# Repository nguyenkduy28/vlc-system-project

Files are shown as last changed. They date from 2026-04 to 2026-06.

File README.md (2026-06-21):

# Hệ thống truyền thông ánh sáng nhìn thấy (VLC/OWC)

Đây là repository đồ án thiết kế hệ thống truyền thông quang không dây sử dụng ánh sáng nhìn thấy. Hệ thống gồm bo mạch phát/thu, firmware cho STM32F407VET6, chương trình giám sát trên máy tính và tài liệu phục vụ thiết kế, mô phỏng, đo kiểm.

## 1. Tổng quan hệ thống

Hệ thống truyền dữ liệu theo phương pháp điều chế OOK (On-Off Keying):

- Khối phát tạo sóng mang quang bằng PWM, đóng/ngắt sóng mang theo từng bit dữ liệu.
- Khối thu chuyển tín hiệu quang thành tín hiệu điện, tạo dữ liệu bit từ số cạnh thu được trong mỗi chu kỳ bit.
- STM32 thực hiện đóng gói frame, phát dữ liệu, đồng bộ frame thu, kiểm tra checksum và thống kê chất lượng liên kết.
- Máy tính giao tiếp với bo mạch qua UART để gửi lệnh, quan sát frame, điện áp, RTC, lỗi và các chỉ số BER/PER.

Định dạng frame hiện tại:

```text
AA AA AA | D5 | LEN | PAYLOAD | CHECKSUM
```

Trong đó:

- Preamble: 3 byte `0xAA`.
- Sync: `0xD5`.
- LEN: số byte payload, tối đa 32 byte.
- CHECKSUM: `(LEN + tổng các byte PAYLOAD) mod 256`.

Thông số mặc định của firmware:

| Thông số | Giá trị |
|---|---:|
| Vi điều khiển | STM32F407VET6 |
| Tốc độ bit | 100 kbit/s |
| Tần số tick TIM2 | 100 kHz |
| Sóng mang PWM TIM1 | khoảng 1 MHz |
| Ngưỡng nhận bit theo số cạnh | 6 cạnh/bit |
| Điện áp DAC threshold | 1650 mV |
| UART | 115200 baud |

## 2. Cấu trúc repository

```text
vlc-system-project/
├── firmware/   Firmware STM32CubeIDE cho STM32F407VET6
├── gui/        Các chương trình Python giao tiếp và giám sát UART
├── hardware/   Schematic, PCB, thư viện linh kiện và output Altium
├── ref/        Datasheet, tài liệu tham khảo, ảnh đo và kết quả mô phỏng
└── README.md   Tài liệu tổng quan repository
```

### `firmware/`

Project STM32CubeIDE chính nằm trong thư mục này.

- `OWC_Project.ioc`: cấu hình ngoại vi STM32CubeMX.
- `Core/Src/main.c`: khởi tạo ngoại vi và vòng lặp chương trình.
- `Core/Src/app_tasks.c`: điều phối ứng dụng, xử lý UART command và xuất log.
- `Core/Src/app_protocol.c`: định dạng frame và checksum.
- `Core/Src/vlc_tx.c`: phát frame OOK.
- `Core/Src/vlc_rx.c`: lấy mẫu tín hiệu thu và quản lý queue frame/lỗi.
- `Core/Src/rx_sync.c`: máy trạng thái đồng bộ và giải mã frame.
- `Core/Src/bsp_*.c`: UART, ADC monitor, DAC threshold và RTC.
- `Core/Inc/app_config.h`: các thông số cấu hình chính.
- `Drivers/`: thư viện HAL và CMSIS của STMicroelectronics.
- `Debug/`: output sinh ra khi build, không phải mã nguồn chính.

Các tài liệu luồng xử lý nằm tại:

- `firmware/overview.md`
- `firmware/flowtx.md`
- `firmware/flowrx.md`

### `gui/`

Các GUI được viết bằng Python/Tkinter, nhận log từ UART và hiển thị dữ liệu bằng Matplotlib.

Ba chương trình phù hợp với từng chế độ firmware:

| Chế độ firmware | GUI đề xuất |
|---|---|
| `APP_BOARD_ROLE_TX_ONLY` | `owc_tx_only_gui_v5_rtc.py` |
| `APP_BOARD_ROLE_RX_ONLY` | `owc_rx_only_gui_demo_v1.py` hoặc `owc_rx_monitor.py` |
| `APP_BOARD_ROLE_TX_RX_LOOPBACK` | `owc_loopback_gui_v2_tx_rx_tabs.py` |

Các file có hậu tố `v2`, `v3`, `fixed`, `demo` là các phiên bản phát triển được lưu lại để đối chiếu. Khi chạy thử nên chọn file mới nhất phù hợp với `APP_BOARD_ROLE`.

### `hardware/`

Thiết kế phần cứng được thực hiện bằng Altium Designer. Project chính:

```text
hardware/PCB_STM32F4/PCB_STM32F4.PrjPcb
```

Các sheet chính gồm:

- `BLOCK DIAGRAM.SchDoc`: sơ đồ khối hệ thống.
- `MCU INTERFACE.SchDoc`: STM32 và các kết nối ngoại vi.
- `Transmitter_MD.SchDoc`: mạch phát quang.
- `Receiver_VLC.SchDoc`: mạch thu quang.
- `PW SUPPLY.SchDoc`, `PWR_AFE.SchDoc`: nguồn và analog front-end.
- `VOLTAGE_MONITOR.SchDoc`: giám sát các đường nguồn.
- `UART TO USB LOG.SchDoc`: giao tiếp UART–USB.
- `PCB1.PcbDoc`: layout PCB.
- `VLC_SYSTEM.pdf`: bản xuất sơ đồ hệ thống.

Thư mục `History/` và `Project Outputs for PCB_STM32F4/` chứa lịch sử thiết kế và các báo cáo/output do Altium tạo.

### `ref/`

Chứa tài liệu phục vụ lựa chọn linh kiện và kiểm chứng thiết kế:

- Datasheet LED, photodiode, transistor, driver và IC nguồn.
- Tài liệu thiết kế transimpedance amplifier và mạch lọc.
- Tài liệu STM32F407.
- File mô phỏng TINA/Multisim.
- BOM, ảnh oscilloscope, ảnh PCB và sơ đồ trình tự hoạt động.

## 3. Build và nạp firmware

Yêu cầu:

- STM32CubeIDE.
- ST-LINK hoặc bộ nạp tương thích.
- Bo mạch sử dụng STM32F407VET6.

Các bước thực hiện:

1. Mở STM32CubeIDE và import thư mục `firmware/` dưới dạng project hiện có.
2. Chọn chế độ bo mạch trong `firmware/Core/Inc/app_config.h`:

   ```c
   #define APP_BOARD_ROLE APP_BOARD_ROLE_TX_ONLY
   // hoặc APP_BOARD_ROLE_RX_ONLY
   // hoặc APP_BOARD_ROLE_TX_RX_LOOPBACK
   ```

3. Build cấu hình Debug.
4. Kết nối ST-LINK, nạp chương trình và reset bo mạch.
5. Kết nối UART2 với máy tính ở baud rate `115200`.

Không thay đổi code trong `Drivers/` nếu không cần thiết. Các file chứa marker `USER CODE BEGIN/END` là file do STM32CubeMX quản lý; phần tùy chỉnh nên được đặt trong vùng user code để tránh mất khi generate lại.

## 4. Chạy GUI trên máy tính

Yêu cầu Python 3.9 trở lên. Cài các thư viện cần thiết:

```powershell
python -m pip install pyserial matplotlib
```

Ví dụ chạy GUI loopback:

```powershell
python gui/owc_loopback_gui_v2_tx_rx_tabs.py
```

Hoặc chạy GUI theo từng phía:

```powershell
python gui/owc_tx_only_gui_v5_rtc.py
python gui/owc_rx_only_gui_demo_v1.py
```

Sau khi GUI mở:

1. Chọn đúng cổng COM của bo mạch.
2. Đặt baud rate `115200`.
3. Nhấn **Connect**.
4. Kiểm tra log `role` để xác nhận GUI và firmware đang dùng cùng chế độ.

Các lệnh UART được firmware hỗ trợ gồm nhóm điều khiển TX (`tx_payload`, `tx_start`, `tx_stop`, `tx_single`, `tx_carrier_on`, `tx_carrier_off`, `tx_status`) và nhóm RTC (`rtc_get`, `rtc_set`, `rtc_reset`, `rtc_bkp`). Khả năng sử dụng lệnh TX phụ thuộc vào `APP_BOARD_ROLE`.

## 5. Log UART chính

Firmware xuất log định kỳ hoặc theo sự kiện:

| Log | Nội dung |
|---|---|
| `role` | Chế độ hiện tại của firmware |
| `alive_tx`, `alive_rx` | Bộ đếm và trạng thái hoạt động |
| `tx_frame` | Frame đang phát |
| `expected_tx_frame` | Frame tham chiếu ở phía thu |
| `last_rx`, `rx_frame` | Frame nhận gần nhất |
| `link_stats`, `link_quality` | BER, PER và thống kê payload |
| `err_summary`, `err_frame` | Thống kê và chi tiết lỗi |
| `adc_mv` | Điện áp các kênh giám sát |
| `dac_mv` | Điện áp ngưỡng comparator |
| `rtc` | Thời gian và trạng thái RTC/LSE/VBAT |

## 6. Kiểm thử cơ bản

### TX-only

- Kiểm tra PWM carrier tại đầu ra TIM1.
- Quan sát `tx_frame` và bộ đếm `tx_frames`.
- Thử `tx_start`, `tx_stop`, `tx_single` và thay payload.
- Đối chiếu tốc độ bit và dạng sóng OOK trên oscilloscope.

### RX-only

- Cấp tín hiệu quang từ bộ phát vào mạch thu.
- Theo dõi `last_edge_delta`, `last_raw_bit` và trạng thái FSM.
- Kiểm tra frame nhận, checksum, frame error và BER/PER.
- Điều chỉnh ngưỡng DAC khi chất lượng tín hiệu thay đổi.

### Loopback

- Build firmware với `APP_BOARD_ROLE_TX_RX_LOOPBACK`.
- So sánh trực tiếp frame TX và RX trong GUI loopback.
- Theo dõi lỗi theo vị trí bit, chất lượng liên kết và các đường nguồn.

## 7. Ghi chú

- Giá trị điện áp, ngưỡng cạnh và DAC cần được hiệu chỉnh theo phiên bản phần cứng và kết quả đo thực tế.
- Không commit thêm output build hoặc file tạm của IDE vào phần mã nguồn phát hành.
- Datasheet và tài liệu trong `ref/` thuộc về các nhà sản xuất hoặc tác giả tương ứng và chỉ được lưu để tham khảo kỹ thuật.

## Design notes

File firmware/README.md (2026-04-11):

# vlc-system-project
# VLC System Project

Graduation project for a Visible Light Communication system.

## Scope
This repository contains:
- Hardware design
- Firmware for STM32-based TX/RX
- PC software tools and GUI
- Test results and measurement data
- Project documentation

## Main modules
- Power management
- Optical transmitter
- Optical receiver
- ADC/comparator signal path
- STM32 firmware
- PC monitoring software

## Repository structure
- docs/: thesis, reports, block diagrams, datasheets
- hardware/: schematic, PCB, BOM, simulation, library
- firmware/: STM32 source code for TX/RX
- software/: PC tools, GUI, logger, analysis
- test/: BER, waveform, power, link validation
- production/: manufacturing outputs

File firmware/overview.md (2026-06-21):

# Overview Firmware OWC Project

Tài liệu này tóm tắt các phần quan trọng nhất của firmware OWC để dùng cho slide overview. Nội dung tập trung vào kiến trúc tổng quan, luồng TX/RX, FSM RX, giao tiếp UART, và các khối giám sát hệ thống.

---

## 1. Tổng quan kiến trúc firmware

Firmware được xây dựng trên STM32F407 và chia thành các khối chính:

- `main.c`: khởi tạo hệ thống và chạy vòng lặp chính.
- `app_tasks.c`: điều phối init, start, ISR dispatch, xử lý UART và log foreground.
- `vlc_tx.c`: phát frame OOK theo bit tick.
- `vlc_rx.c`: đọc edge-count TIM4, tạo raw bit và đẩy vào FSM RX.
- `rx_sync.c`: giải mã frame theo FSM.
- `app_protocol.c`: build frame và checksum dùng chung cho TX/RX.
- `bsp_uart.c`, `bsp_adc_monitor.c`, `bsp_dac_threshold.c`, `bsp_rtc.c`: dịch vụ nền.

```mermaid
%%{init: {"themeVariables": {"fontFamily": "Times New Roman", "fontSize": "18px"}}}%%
flowchart TD
    A["main.c"] --> B["app_tasks_init()"]
    B --> C["app_tasks_start()"]
    C --> D["TIM2 ISR"]
    D --> E["TX path"]
    D --> F["RX path"]
    C --> G["Foreground loop"]
    G --> H["UART logs"]
    G --> I["UART commands"]
    E --> J["TIM1 carrier OOK"]
    F --> K["TIM4 edge-count"]
    K --> L["rx_sync FSM"]
```

---

## 2. Cơ chế board role

Firmware hỗ trợ 3 chế độ biên dịch:

- `APP_BOARD_ROLE_TX_ONLY`
- `APP_BOARD_ROLE_RX_ONLY`
- `APP_BOARD_ROLE_TX_RX_LOOPBACK`

```mermaid
%%{init: {"themeVariables": {"fontFamily": "Times New Roman", "fontSize": "18px"}}}%%
flowchart TD
    A["TIM2 IRQ"] --> B{"APP_BOARD_ROLE?"}
    B -- "TX_ONLY" --> C["vlc_tx_on_bit_tick()"]
    B -- "RX_ONLY" --> D["vlc_rx_on_bit_tick()"]
    B -- "TX_RX_LOOPBACK" --> E["vlc_rx_on_bit_tick()"]
    E --> F["vlc_tx_on_bit_tick()"]
```

Ý nghĩa:

- `TX_ONLY`: chỉ phát, không chạy RX FSM trong ISR.
- `RX_ONLY`: chỉ thu, không phát bit trong ISR.
- `TX_RX_LOOPBACK`: chạy cả RX và TX, dùng cho kiểm thử nội bộ.

---

## 3. Flow phát TX

TX dùng điều chế OOK:

- bit `1` -> `TIM1 CCR1 = 84`
- bit `0` -> `TIM1 CCR1 = 0`

Frame TX:

```text
AA AA AA | D5 | LEN | PAYLOAD | CHECKSUM
```

```mermaid
%%{init: {"themeVariables": {"fontFamily": "Times New Roman", "fontSize": "18px"}}}%%
flowchart LR
    A["TIM2 tick"] --> B["vlc_tx_on_bit_tick()"]
    B --> C{"carrier_test?"}
    C -- "Yes" --> D["CCR1 = 84"]
    C -- "No" --> E{"tx_enabled?"}
    E -- "No" --> F["CCR1 = 0"]
    E -- "Yes" --> G{"bit = 1?"}
    G -- "Yes" --> H["CCR1 = 84"]
    G -- "No" --> I["CCR1 = 0"]
    H --> J["Advance bit index"]
    I --> J
    J --> K{"End of frame?"}
    K -- "No" --> L["Next tick"]
    K -- "Yes" --> M["Reset index + tx_frames++"]
```

---

## 4. Flow thu RX

RX dùng TIM4 đếm cạnh trên PB6.

Mỗi `TIM2` tick:

1. Đọc counter TIM4.
2. Tính `edge_delta`.
3. So sánh với `APP_RX_EDGE_THRESHOLD = 6`.
4. Tạo `raw_bit`.
5. Đẩy vào `rx_sync_on_tick()`.

```mermaid
%%{init: {"themeVariables": {"fontFamily": "Times New Roman", "fontSize": "18px"}}}%%
flowchart TD
    A["TIM2 tick"] --> B["Read TIM4 counter"]
    B --> C["Compute edge_delta"]
    C --> D{"edge_delta >= 6?"}
    D -- "Yes" --> E["raw_bit = 1"]
    D -- "No" --> F["raw_bit = 0"]
    E --> G["rx_sync_on_tick()"]
    F --> G
    G --> H{"Frame result?"}
    H -- "Valid" --> I["Push RX queue"]
    H -- "Frame error" --> J["Push error event"]
    H -- "Checksum error" --> K["Push error event"]
```

---

## 5. FSM đồng bộ RX

FSM RX là phần quan trọng nhất của khối thu.

Các state:

- `RX_SYNC_WAIT_ACTIVITY`
- `RX_SYNC_DETECT_PREAMBLE`
- `RX_SYNC_LOCK_BIT_TIMING`
- `RX_SYNC_READ_SYNC`
- `RX_SYNC_READ_LEN`
- `RX_SYNC_READ_PAYLOAD`
- `RX_SYNC_READ_CHECKSUM`

```mermaid
%%{init: {"themeVariables": {"fontFamily": "Times New Roman", "fontSize": "18px"}}}%%
stateDiagram-v2
    [*] --> WAIT_ACTIVITY
    WAIT_ACTIVITY --> DETECT_PREAMBLE : raw_bit=1
    WAIT_ACTIVITY --> WAIT_ACTIVITY : raw_bit=0

    DETECT_PREAMBLE --> READ_SYNC : found 0xAAAAAA
    DETECT_PREAMBLE --> DETECT_PREAMBLE : continue shift

    READ_SYNC --> READ_LEN : sync = 0xD5
    READ_SYNC --> WAIT_ACTIVITY : sync error

    READ_LEN --> READ_PAYLOAD : len valid
    READ_LEN --> WAIT_ACTIVITY : length error

    READ_PAYLOAD --> READ_CHECKSUM : payload done
    READ_CHECKSUM --> WAIT_ACTIVITY : checksum checked
```

Checksum:

```text
CHECKSUM = (LEN + sum(PAYLOAD)) mod 256
```

Frame hợp lệ được đẩy vào queue để foreground loop log ra `last_rx`, `rx_frame`, `link_stats`, `link_quality`.

---

## 6. UART log và command

Firmware không in log trong ISR. Tất cả log và command được xử lý ở foreground loop.

```mermaid
%%{init: {"themeVariables": {"fontFamily": "Times New Roman", "fontSize": "18px"}}}%%
flowchart TD
    A["UART byte"] --> B["Line buffer"]
    B --> C["Command line"]
    C --> D{"RTC command?"}
    D -- "Yes" --> E["rtc_get / rtc_set / rtc_reset / rtc_bkp"]
    D -- "No" --> F{"TX-capable role?"}
    F -- "TX_ONLY / TX_RX_LOOPBACK" --> G["tx_payload / tx_start / tx_stop / tx_single"]
    F -- "RX_ONLY" --> H["Ignore TX command"]
    E --> I["Print response"]
    G --> I
    H --> I
```

Nhóm lệnh TX được hỗ trợ trong cả `APP_BOARD_ROLE_TX_ONLY` và
`APP_BOARD_ROLE_TX_RX_LOOPBACK`. Riêng `APP_BOARD_ROLE_RX_ONLY` không có khối
phát nên firmware bỏ qua các lệnh TX và trả response lỗi command không hỗ trợ.

Các log chính:

- `role ...`
- `alive_tx ...` hoặc `alive_rx ...`
- `tx_frame ...`
- `expected_tx_frame ...`
- `last_rx ...`
- `rx_frame ...`
- `link_stats ...`
- `link_quality ...`
- `err_summary ...`
- `adc_mv ...`
- `dac_mv ...`
- `rtc ...`

---

## 7. Khối giám sát hệ thống

Hai khối nền giúp theo dõi trạng thái board:

- ADC monitor:
  - `rx_out_a`
  - `vmon_bu`
  - `vmon_bu_3v`
  - `vmon_main_sys`
  - `vmon_main`
  - `vmon_5v_sys`
  - `vmon_3v3_sys`
- DAC threshold:
  - mặc định `1650 mV`
- RTC:
  - dùng LSE `32.768 kHz`
  - backup register để giữ trạng thái thời gian khi VBAT còn

```mermaid
%%{init: {"themeVariables": {"fontFamily": "Times New Roman", "fontSize": "18px"}}}%%
flowchart LR
    A["ADC monitor"] --> B["adc_mv"]
    C["DAC threshold"] --> D["dac_mv"]
    E["RTC LSE/VBAT"] --> F["rtc"]
```

---

## 8. Điểm nhấn để đưa vào slide

Nếu chỉ chọn phần quan trọng nhất cho slide overview, nên ưu tiên:

1. Kiến trúc firmware.
2. Cơ chế board role.
3. Flow TX OOK.
4. Flow RX edge-count.
5. FSM RX.
6. UART log và command.

Đây là các phần thể hiện rõ nhất cách firmware vận hành và đủ để người xem hiểu hệ thống ngay từ cái nhìn đầu.

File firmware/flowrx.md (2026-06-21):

# RX Flow - OWC Project

Tài liệu này mô tả luồng xử lý RX của firmware truyền thông quang OWC trên STM32F407. Nội dung tập trung vào chế độ `APP_BOARD_ROLE_RX_ONLY`, đồng thời vẫn nêu rõ phần dùng chung với chế độ loopback để tiện cho report kỹ thuật và debug hệ thống.

---

## 1. Tổng quan

Luồng RX trong firmware được chia thành các phần chính:

1. Khởi tạo hệ thống, bật các ngoại vi hỗ trợ thu và giám sát.
2. Đọc xung cạnh từ `TIM4` trên chân `PB6`.
3. Mỗi nhịp `TIM2`, chuyển số cạnh đo được thành `raw_bit`.
4. Đưa `raw_bit` vào máy trạng thái `rx_sync`.
5. Nếu frame hợp lệ, đẩy vào queue để xử lý ở foreground.
6. Nếu lỗi sync hoặc checksum, tạo error event để log sau trong main loop.

Các ràng buộc kỹ thuật chính của khối RX:

* `TIM4` dùng edge-count để đếm cạnh từ tín hiệu thu.
* `APP_RX_EDGE_THRESHOLD = 6` dùng để chuyển delta cạnh thành bit 0/1.
* `TIM2` vẫn là bit tick 100 kHz.
* RX không in UART trong ISR.
* Các frame hợp lệ và frame lỗi đều được đưa ra foreground loop để log, tránh làm nặng ngắt.

---

## 2. Các khối chính trong luồng RX

| Khối | Vai trò |
| --- | --- |
| `main.c` | Khởi tạo hệ thống và chạy vòng lặp chính |
| `app_tasks.c/h` | Điều phối init, start, ISR theo board role, xử lý log UART |
| `vlc_rx.c/h` | Đọc TIM4, tạo raw bit, quản lý queue frame và error event |
| `rx_sync.c/h` | FSM đồng bộ preamble, sync, length, payload, checksum |
| `app_protocol.c/h` | Cung cấp payload/frame chuẩn để so sánh |
| `vlc_tx.c/h` | Cung cấp frame TX snapshot cho log so sánh và thống kê |
| `bsp_uart.c/h` | In log và nhận command UART |
| `bsp_adc_monitor.c/h` | Giám sát điện áp hệ thống |
| `bsp_dac_threshold.c/h` | Theo dõi ngưỡng DAC |
| `bsp_rtc.c/h` | Cung cấp timestamp cho log |

Trong chế độ `APP_BOARD_ROLE_RX_ONLY`, khối RX là thành phần trung tâm. Firmware vẫn giữ các khối hỗ trợ như ADC, DAC và RTC để phục vụ giám sát hệ thống và đồng bộ log.

---

## 3. Luồng khởi động RX

Khi firmware bắt đầu chạy, `main.c` thực hiện các bước khởi tạo HAL, clock hệ thống, GPIO và các ngoại vi cần thiết. Sau đó, `app_tasks_init()` khởi tạo các module ứng dụng, bao gồm UART, RTC, ADC monitor, DAC threshold, TX và RX. Tiếp theo, `app_tasks_start()` bật các runtime module theo `APP_BOARD_ROLE`.

```mermaid
%%{init: {"themeVariables": {"fontFamily": "Times New Roman", "fontSize": "18px"}}}%%
flowchart TD
    A["main()"] --> B["HAL_Init()"]
    B --> C["SystemClock_Config()"]
    C --> D["GPIO Init"]
    D --> E["DMA Init"]
    E --> F["TIM1 Init"]
    F --> G["TIM2 Init"]
    G --> H["ADC1 Init"]
    H --> I["UART2 Init"]
    I --> J["DAC Init"]
    J --> K["TIM4 Init"]
    K --> L["app_tasks_init()"]
    L --> L1["bsp_uart_init()"]
    L1 --> L2["bsp_rtc_init()"]
    L2 --> L3["bsp_adc_monitor_init()"]
    L3 --> L4["bsp_dac_threshold_init()"]
    L4 --> L5["vlc_tx_init()"]
    L5 --> L6["vlc_rx_init()"]
    L6 --> M["app_tasks_start()"]
    M --> N["Set DAC threshold"]
    N --> O["Start ADC monitor"]
    O --> P{"Board role?"}
    P -- "RX_ONLY" --> Q["Start RX module"]
    P -- "TX_RX_LOOPBACK" --> R["Start TX + RX modules"]
    P -- "TX_ONLY" --> S["Start TX module"]
    Q --> T["Start TIM2 interrupt"]
    R --> T
    S --> T
    T --> U["Main loop"]
    U --> V["app_tasks_process()"]
```

**Hình x. Luồng khởi động firmware khi chạy theo nhánh RX.**

Trong chế độ RX, `vlc_rx_init(htim4)` thiết lập queue frame, queue error event và reset trạng thái FSM. `vlc_rx_start()` sau đó khởi động `TIM4` ở chế độ edge-count để đo số cạnh của tín hiệu quang thu được.

---

## 4. Luồng thu bit RX

Mỗi lần `TIM2` phát sinh ngắt, firmware gọi callback timer. Trong chế độ `APP_BOARD_ROLE_RX_ONLY`, ISR chỉ gọi `vlc_rx_on_bit_tick()` để lấy mẫu cửa sổ bit hiện tại từ `TIM4`.

```mermaid
%%{init: {"themeVariables": {"fontFamily": "Times New Roman", "fontSize": "18px"}}}%%
flowchart TD
    A["TIM2 IRQ"] --> B["Timer callback"]
    B --> C["Read TIM4 counter"]
    C --> D["Compute edge delta"]
    D --> E{"delta >= threshold?"}
    E -- "Yes" --> F["raw_bit = 1"]
    E -- "No" --> G["raw_bit = 0"]
    F --> H["Update RX stats"]
    G --> H
    H --> I["rx_sync_on_tick(raw_bit)"]
    I --> J{"Frame result?"}
    J -- "Valid frame" --> K["Push to RX queue"]
    J -- "Frame error" --> L["Push error event"]
    J -- "Checksum error" --> M["Push checksum event"]
    K --> N["End ISR"]
    L --> N
    M --> N
```

**Hình x. Lưu đồ xử lý bit RX trong mỗi chu kỳ ngắt TIM2.**

Ở mỗi nhịp, firmware đọc giá trị counter của `TIM4`, tính chênh lệch so với lần đọc trước, rồi so sánh với `APP_RX_EDGE_THRESHOLD = 6`. Nếu số cạnh đủ lớn, bit được suy ra là `1`, ngược lại là `0`. Cách làm này giúp RX không cần lấy mẫu biên độ analog trực tiếp, mà dựa vào số cạnh thu được từ đường quang.

---

## 5. Cấu trúc frame RX

RX giải mã frame theo cùng định dạng với TX:

```text
AA AA AA | D5 | LEN | PAYLOAD | CHECKSUM
```

Trong đó:

| Trường | Ý nghĩa |
| --- | --- |
| `AA AA AA` | Preamble để phát hiện khung bắt đầu |
| `D5` | Sync byte |
| `LEN` | Độ dài payload |
| `PAYLOAD`  | Dữ liệu cần nhận |
| `CHECKSUM` | Byte kiểm tra lỗi |

```mermaid
%%{init: {"themeVariables": {"fontFamily": "Times New Roman", "fontSize": "18px"}}}%%
flowchart LR
    A["Preamble 1"] --> B["Preamble 2"]
    B --> C["Preamble 3"]
    C --> D["Sync byte"]
    D --> E["Length"]
    E --> F["Payload"]
    F --> G["Checksum"]
```

**Hình x. Cấu trúc frame thu được bởi khối RX.**

RX dùng cùng công thức checksum với TX:

```text
CHECKSUM = (LEN + sum(PAYLOAD)) mod 256
```

Với payload mặc định `55 A5 3C C3`, frame hợp lệ sẽ có checksum `FD`.

---

## 6. Máy trạng thái đồng bộ RX

Khối `rx_sync` là trung tâm của luồng RX. Nó nhận `raw_bit` từ `vlc_rx_on_bit_tick()` và giải mã dần thành byte, rồi thành frame.

Các trạng thái chính:

| State | Ý nghĩa |
| ----- | --- |
| `RX_SYNC_WAIT_ACTIVITY` | Chờ có hoạt động trên đường RX |
| `RX_SYNC_DETECT_PREAMBLE` | Tìm chuỗi `AA AA AA` bằng shift 24-bit |
| `RX_SYNC_LOCK_BIT_TIMING` | Trạng thái khóa bit timing trung gian |
| `RX_SYNC_READ_SYNC` | Đọc byte sync `D5` |
| `RX_SYNC_READ_LEN` | Đọc độ dài payload |
| `RX_SYNC_READ_PAYLOAD` | Đọc các byte payload |
| `RX_SYNC_READ_CHECKSUM` | Đọc byte checksum và kiểm tra |

```mermaid
%%{init: {"themeVariables": {"fontFamily": "Times New Roman", "fontSize": "18px"}}}%%
stateDiagram-v2
    [*] --> WAIT_ACTIVITY
    WAIT_ACTIVITY --> DETECT_PREAMBLE : raw_bit = 1
    WAIT_ACTIVITY --> WAIT_ACTIVITY : raw_bit = 0

    DETECT_PREAMBLE --> READ_SYNC : found 0xAAAAAA
    DETECT_PREAMBLE --> DETECT_PREAMBLE : not found

    READ_SYNC --> READ_LEN : value = 0xD5
    READ_SYNC --> WAIT_ACTIVITY : sync error

    READ_LEN --> READ_PAYLOAD : 1..APP_MAX_PAYLOAD_LEN
    READ_LEN --> WAIT_ACTIVITY : length error

    READ_PAYLOAD --> READ_CHECKSUM : enough bytes
    READ_CHECKSUM --> WAIT_ACTIVITY : checksum done
```

**Hình x. FSM đồng bộ và giải mã frame RX.**

Hai điểm quan trọng trong FSM:

1. `WAIT_ACTIVITY` không làm mất bit `1` đầu tiên khi bắt đầu preamble.
2. Sau khi phát hiện `AA AA AA`, FSM chuyển sang `READ_SYNC` mà không bỏ mất bit kế tiếp.

Khi `READ_CHECKSUM` nhận đủ byte cuối:

* Nếu checksum đúng, `result.has_frame = 1`.
* Nếu sai checksum, `result.checksum_error = 1`.
* Nếu sai sync hoặc sai length, `result.frame_error = 1`.

---

## 7. Luồng xử lý frame hợp lệ và lỗi

```mermaid
%%{init: {"themeVariables": {"fontFamily": "Times New Roman", "fontSize": "18px"}}}%%
flowchart TD
    A["rx_sync_on_tick()"] --> B{"has_frame?"}
    B -- "Yes" --> C["Increment rx_frames"]
    C --> D["Push valid frame to queue"]
    B -- "No" --> E{"frame_error?"}
    E -- "Yes" --> F["Increment frame_errors"]
    F --> G["Push frame error event"]
    E -- "No" --> H{"checksum_error?"}
    H -- "Yes" --> I["Increment checksum_errors"]
    I --> J["Push checksum error event"]
    H -- "No" --> K["No event"]
```

**Hình x. Xử lý kết quả sau khi FSM giải mã một bit window.**

Khi một frame hợp lệ xuất hiện, `vlc_rx.c` đẩy frame vào queue valid frame và gán `rx_frame_id` theo bộ đếm quan sát riêng `s_rx_observed_frames`. Nếu là lỗi, firmware không in UART ngay trong ISR mà đẩy error event sang queue riêng để xử lý ở foreground loop.

---

## 8. Luồng UART điều khiển và log RX

UART command được xử lý trong foreground loop tại `app_tasks_process()`. Firmware không xử lý UART trong ISR để tránh blocking và để giữ `TIM2` ngắn.

```mermaid
%%{init: {"themeVariables": {"fontFamily": "Times New Roman", "fontSize": "18px"}}}%%
flowchart TD
    A["UART RX byte"] --> B["Line buffer"]
    B --> C["Command line"]
    C --> D{"RTC command?"}
    D -- "Yes" --> E["Handle RTC command"]
    D -- "No" --> F{"Board role RX_ONLY?"}
    F -- "Yes" --> G["RX processing only"]
    F -- "No" --> H["Loopback / TX path"]
    E --> I["Print response"]
    G --> I
    H --> I
```

**Hình x. Luồng xử lý UART command trong foreground loop.**

Các log chính của RX gồm:

```text
role board_role=RX_ONLY
alive_rx rx_frames=<N> frame_errors=<N> checksum_errors=<N> rx_sync_state=<N> last_edge_delta=<N> last_raw_bit=<N>
expected_tx_frame len=<N> payload=<HEX...> checksum=<XX> frame=<HEX...>
last_rx len=<N> payload=<HEX...>
rx_frame rx_frame_id=<N> len=<N> payload=<HEX...> checksum=<XX> frame=<HEX...>
link_stats payload_bits=<N> payload_bit_errors=<N> payload_ber_ppm=<N> invalid_frames=<N> payload_mismatch_frames=<N> good_payload_frames=<N>
link_quality rx_total_observed=<N> per_ppm=<N>
err_summary queued=<N> printed=<N> suppressed=<N>
err_frame ...
err_bits ...
adc_mv ...
dac_mv threshold=1650
rtc ...
```

Log `expected_tx_frame` rất quan trọng trong chế độ RX_ONLY vì board RX không phát dữ liệu thật, nhưng vẫn cần biết frame chuẩn để so sánh và tính thống kê chất lượng liên kết.

---

## 9. Queue frame và error event

RX dùng hai queue riêng:

1. Queue frame hợp lệ: chứa các frame decode thành công.
2. Queue error event: chứa event lỗi để log ở foreground loop.

```mermaid
%%{init: {"themeVariables": {"fontFamily": "Times New Roman", "fontSize": "18px"}}}%%
flowchart LR
    A["Valid frame"] --> B["RX queue"]
    C["Frame error"] --> D["Error event queue"]
    E["Checksum error"] --> D
    B --> F["Foreground log"]
    D --> G["Foreground error log"]
```

**Hình x. Cơ chế queue trong khối RX.**

Thiết kế này giúp ISR ngắn, giảm nguy cơ nghẽn UART và tránh in log nặng ngay trong ngắt `TIM2`.

---

## 10. Thống kê chất lượng link

Đối với frame hợp lệ, firmware so sánh payload nhận được với payload chuẩn từ `app_protocol`. Từ đó, hệ thống cập nhật:

* `payload_bits`
* `payload_bit_errors`
* `invalid_frames`
* `payload_mismatch_frames`
* `good_payload_frames`

Sau đó, firmware in ra:

```text
link_stats payload_bits=<N> payload_bit_errors=<N> payload_ber_ppm=<N> invalid_frames=<N> payload_mismatch_frames=<N> good_payload_frames=<N>
```

Và:

```text
link_quality rx_total_observed=<N> per_ppm=<N>
```

Chỉ số này giúp GUI và người dùng đánh giá chất lượng đường truyền mà không cần phân tích từng frame thủ công.

---

## 11. Tiêu chí kiểm thử RX_ONLY

Khi kiểm thử chế độ `APP_BOARD_ROLE_RX_ONLY`, cần quan sát:

1. `rx_frames` tăng đều khi board RX nhận được tín hiệu từ board TX.
2. `last_rx` hiển thị đúng payload mặc định hoặc payload vừa được phát.
3. `expected_tx_frame` luôn đúng frame chuẩn để so sánh.
4. `frame_errors` và `checksum_errors` thấp hoặc bằng 0 khi tín hiệu ổn định.
5. `rx_sync_state`, `last_edge_delta`, `last_raw_bit` thay đổi hợp lý theo đường tín hiệu.
6. Không có UART logging bên trong ISR.

```text
expected_tx_frame len=4 payload=55 A5 3C C3 checksum=FD frame=AA AA AA D5 04 55 A5 3C C3 FD
last_rx len=4 payload=55 A5 3C C3
```

---

## 12. Kết luận

Luồng RX của OWC Project được thiết kế theo hướng tách rõ ba tầng: đo cạnh ở `TIM4`, chuyển đổi thành bit ở `TIM2`, và giải mã frame bằng FSM `rx_sync`. Cách chia này giúp firmware giữ ISR ngắn, dễ debug và vẫn đảm bảo tính ổn định cho hệ thống OOK. Các frame hợp lệ và các lỗi giải mã đều được đưa sang foreground loop để log, nhờ đó UART không làm ảnh hưởng tới realtime của đường thu.

Thiết kế này đáp ứng tốt các yêu cầu của hệ thống truyền thông quang: decode frame theo đúng cấu trúc `AA AA AA | D5 | LEN | PAYLOAD | CHECKSUM`, hỗ trợ thống kê chất lượng link, và giữ khả năng mở rộng cho GUI cũng như các chế độ board role khác.

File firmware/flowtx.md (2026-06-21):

# TX Flow - OWC Project

Tài liệu này mô tả luồng xử lý TX của firmware truyền thông quang không dây OWC trên vi điều khiển STM32F407. Nội dung tập trung vào chế độ `APP_BOARD_ROLE_TX_ONLY`, cơ chế phát dữ liệu OOK bằng timer và cách các lệnh UART điều khiển khối TX trong quá trình chạy runtime.

---

## 1. Tổng quan

Luồng TX trong firmware được chia thành hai phần chính:

1. Khởi tạo hệ thống và bật các ngoại vi phục vụ khối phát.
2. Xử lý theo nhịp ngắt `TIM2` để phát từng bit OOK thông qua `TIM1`.

Các ràng buộc kỹ thuật chính của khối TX:

* `TIM1` tạo sóng mang 1 MHz trên chân `PA8`.
* `TIM2` tạo bit tick 100 kHz.
* Điều chế OOK được thực hiện bằng cách điều khiển `TIM1 CCR1`:

  * Bit `1`: `TIM1 CCR1 = 84`, bật carrier.
  * Bit `0`: `TIM1 CCR1 = 0`, tắt carrier.
* Frame truyền có định dạng:

```text
AA AA AA | D5 | LEN | PAYLOAD | CHECKSUM
```

* Payload mặc định:

```text
55 A5 3C C3
```

* Checksum của payload mặc định là:

```text
FD
```

Nguyên tắc thiết kế quan trọng của firmware là giữ ISR ngắn, không thực hiện UART logging trong ISR và chỉ xử lý các tác vụ thời gian thực tối thiểu trong ngắt `TIM2`.

---

## 2. Các khối chính trong luồng TX

| Khối | Vai trò |
| --- | --- |
| `main.c` | Gọi khởi tạo hệ thống và duy trì vòng lặp chính |
| `app_tasks.c/h` | Điều phối init, start, process và ISR theo board role |
| `vlc_tx.c/h` | Quản lý frame TX và phát từng bit OOK |
| `app_protocol.c/h` | Tạo frame chuẩn và tính checksum |
| `bsp_uart.c/h` | Nhận lệnh UART và in log |
| `bsp_adc_monitor.c/h` | Giám sát điện áp hệ thống |
| `bsp_dac_threshold.c/h` | Thiết lập ngưỡng DAC |
| `bsp_rtc.c/h` | Quản lý RTC và backup domain |

Trong chế độ `APP_BOARD_ROLE_TX_ONLY`, khối TX là thành phần chính được kích hoạt theo chu kỳ bit tick. Các khối còn lại như UART, ADC monitor, DAC threshold và RTC hỗ trợ quá trình debug, giám sát và điều khiển hệ thống.

---

## 3. Luồng khởi động TX

Khi firmware bắt đầu chạy, `main.c` thực hiện các bước khởi tạo HAL, clock hệ thống, GPIO và các ngoại vi cần thiết. Sau đó, `app_tasks_init()` và `app_tasks_start()` được gọi để khởi tạo các module mức ứng dụng và bắt đầu hoạt động theo board role.

```mermaid
%%{init: {"themeVariables": {"fontFamily": "Times New Roman", "fontSize": "18px"}}}%%
flowchart TD
    A["main()"] --> B["HAL_Init()"]
    B --> C["SystemClock_Config()"]
    C --> D["GPIO Init"]
    D --> E["DMA Init"]
    E --> F["TIM1 Init"]
    F --> G["TIM2 Init"]
    G --> H["ADC1 Init"]
    H --> I["UART2 Init"]
    I --> J["DAC Init"]
    J --> K["TIM4 Init"]
    K --> L["app_tasks_init()"]
    L --> L1["bsp_uart_init()"]
    L1 --> L2["bsp_rtc_init()"]
    L2 --> L3["bsp_adc_monitor_init()"]
    L3 --> L4["bsp_dac_threshold_init()"]
    L4 --> L5["vlc_tx_init()"]
    L5 --> L6["vlc_rx_init()"]
    L6 --> M["app_tasks_start()"]
    M --> N["Set DAC threshold"]
    N --> O["Start ADC monitor"]
    O --> P{"Board role?"}
    P -- "TX_ONLY" --> Q["Start TX module"]
    P -- "RX_ONLY" --> R["Start RX module"]
    P -- "TX_RX_LOOPBACK" --> S["Start TX + RX modules"]
    Q --> T["Start TIM2 interrupt"]
    R --> T
    S --> T
    T --> U["Main loop"]
    U --> V["app_tasks_process()"]
```

**Hình x. Luồng khởi động firmware trong chế độ TX.**

Trong quá trình khởi động, `TIM1` được chuẩn bị để tạo carrier 1 MHz, trong khi `TIM2` được dùng làm nguồn bit tick 100 kHz. Sau khi các module ứng dụng được khởi tạo, firmware bắt đầu vòng lặp chính để xử lý UART command, log định kỳ và các tác vụ nền.

---

## 4. Luồng phát bit TX

Mỗi khi `TIM2` phát sinh ngắt, firmware gọi callback xử lý timer. Trong chế độ `APP_BOARD_ROLE_TX_ONLY`, ISR chỉ gọi hàm `vlc_tx_on_bit_tick()` để phát một bit dữ liệu.

```mermaid
%%{init: {"themeVariables": {"fontFamily": "Times New Roman", "fontSize": "18px"}}}%%
flowchart TD
    A["TIM2 IRQ"] --> B["Timer callback"]
    B --> C["Tăng bộ đếm tick"]
    C --> D["vlc_tx_on_bit_tick()"]

    D --> E{"Carrier test on?"}
    E -- "Yes" --> F["Force CCR1 = 84"]
    F --> Z["Kết thúc ISR"]

    E -- "No" --> G{"TX enabled hoặc single frame?"}
    G -- "No" --> H["Force CCR1 = 0"]
    H --> Z

    G -- "Yes" --> I["Đọc bit kế tiếp"]
    I --> J{"Bit = 1?"}

    J -- "Yes" --> K["Set CCR1 = 84"]
    J -- "No" --> L["Set CCR1 = 0"]

    K --> M["Tăng bit index"]
    L --> M

    M --> N{"Hết frame?"}
    N -- "No" --> Z
    N -- "Yes" --> O["Reset bit index"]
    O --> P["Tăng frame counter"]
    P --> Q{"Single frame mode?"}
    Q -- "No" --> Z
    Q -- "Yes" --> R["Disable TX"]
    R --> S["Force CCR1 = 0"]
    S --> Z
```

**Hình x. Lưu đồ phát bit OOK trong mỗi chu kỳ ngắt TIM2.**

Trong mỗi bit tick, firmware kiểm tra trạng thái `carrier_test`. Nếu chế độ test carrier đang bật, firmware giữ `CCR1 = 84` để tạo carrier liên tục. Nếu không ở chế độ test, firmware kiểm tra trạng thái phát dữ liệu. Khi TX được kích hoạt, bit kế tiếp trong frame được đọc theo thứ tự MSB-first. Với bit `1`, firmware ghi `CCR1 = 84` để bật carrier. Với bit `0`, firmware ghi `CCR1 = 0` để tắt carrier.

---

## 5. Cấu trúc frame TX

Frame TX được xây dựng theo định dạng thống nhất giữa TX và RX:

```text
AA AA AA | D5 | LEN | PAYLOAD | CHECKSUM
```

Trong đó:

| Trường | Ý nghĩa |
| --- | --- |
| `AA AA AA` | Preamble, dùng để phía thu phát hiện và đồng bộ frame |
| `D5` | Sync byte, đánh dấu bắt đầu phần dữ liệu thực |
| `LEN` | Độ dài payload |
| `PAYLOAD`  | Dữ liệu cần truyền |
| `CHECKSUM` | Byte kiểm tra lỗi |

```mermaid
%%{init: {"themeVariables": {"fontFamily": "Times New Roman", "fontSize": "18px"}}}%%
flowchart LR
    A["Preamble 1<br/>0xAA"] --> B["Preamble 2<br/>0xAA"]
    B --> C["Preamble 3<br/>0xAA"]
    C --> D["Sync<br/>0xD5"]
    D --> E["Length<br/>LEN"]
    E --> F["Payload"]
    F --> G["Checksum"]
```

**Hình x. Cấu trúc frame truyền của khối TX.**

Checksum được tính theo công thức:

```text
CHECKSUM = (LEN + sum(PAYLOAD)) mod 256
```

Với payload mặc định:

```text
LEN = 04
PAYLOAD = 55 A5 3C C3
```

Checksum được tính như sau:

```text
CHECKSUM = (04 + 55 + A5 + 3C + C3) mod 256
CHECKSUM = FD
```

Do đó frame mặc định hoàn chỉnh là:

```text
AA AA AA D5 04 55 A5 3C C3 FD
```

---

## 6. Luồng build frame TX

Khi khởi tạo TX, module `vlc_tx` lấy payload mặc định từ `app_protocol_get_expected_payload()`, sau đó gọi `app_protocol_build_frame()` để tạo frame truyền hoàn chỉnh.

```mermaid
%%{init: {"themeVariables": {"fontFamily": "Times New Roman", "fontSize": "18px"}}}%%
sequenceDiagram
    participant APP as app_tasks
    participant TX as vlc_tx
    participant P as app_protocol

    APP->>TX: Init TX
    TX->>P: app_protocol_get_expected_payload()
    P-->>TX: Return default payload
    TX->>P: app_protocol_build_frame()
    P-->>TX: Return serialized frame
```

**Hình x. Sequence chart quá trình tạo frame TX khi khởi tạo.**

Việc tách phần build frame sang module `app_protocol` giúp TX và RX dùng chung một định dạng frame và cùng một thuật toán checksum. Cách tổ chức này hạn chế lỗi không đồng bộ giữa phía phát và phía thu.

---

## 7. Luồng UART điều khiển TX

UART command được xử lý trong foreground loop tại `app_tasks_process()`. Firmware không xử lý UART trong ISR nhằm tránh blocking và đảm bảo ngắt `TIM2` luôn đủ ngắn để đáp ứng bit rate 100 kHz.

```mermaid
%%{init: {"themeVariables": {"fontFamily": "Times New Roman", "fontSize": "18px"}}}%%
flowchart TD
    A["UART RX byte"] --> B["Line buffer"]
    B --> C["Command line"]
    C --> D{"RTC command?"}
    D -- "Yes" --> E["Handle RTC command"]
    D -- "No" --> F{"Board role TX_ONLY?"}
    F -- "Yes" --> G["Handle TX command"]
    F -- "No" --> H["Unsupported command"]
    E --> I["Print response"]
    G --> I
    H --> I
```

**Hình x. Luồng xử lý UART command trong foreground loop.**

Các command TX chính được hỗ trợ trong chế độ `APP_BOARD_ROLE_TX_ONLY` gồm:

| Command | Chức năng |
| --- | --- |
| `tx_payload <hex bytes>` | Cập nhật payload và build lại frame TX |
| `tx_start` | Bật chế độ phát liên tục |
| `tx_stop` | Dừng phát dữ liệu |
| `tx_carrier_on` | Bật carrier liên tục để đo kiểm phần cứng |
| `tx_carrier_off` | Tắt chế độ carrier test |
| `tx_single` | Phát một frame đơn |
| `tx_status` | In trạng thái TX hiện tại |

---

## 8. Chi tiết các lệnh UART điều khiển TX

### 8.1. Lệnh `tx_payload`

Lệnh:

```text
tx_payload 11 22 33 44 55 66 77 88
```

Luồng xử lý:

1. Tách từng token hex sau chuỗi `tx_payload`.
2. Parse từng byte bằng `strtoul(..., 16)`.
3. Kiểm tra giá trị sau khi parse không vượt quá `0xFF`.
4. Kiểm tra số byte không vượt quá `APP_MAX_PAYLOAD_LEN`.
5. Gọi `vlc_tx_set_payload(payload, len)` để cập nhật frame TX.
6. Trả về kết quả:

```text
cmd_ok tx_payload len=8 checksum=04
```

Lệnh này cho phép thay đổi dữ liệu phát trong quá trình runtime mà không cần build lại firmware.

### 8.2. Lệnh `tx_start`

Lệnh `tx_start` bật chế độ phát liên tục. Sau khi command được xử lý thành công, TX sẽ phát lặp lại frame hiện tại theo bit tick của `TIM2`.

Phản hồi:

```text
cmd_ok tx_start
```

### 8.3. Lệnh `tx_stop`

Lệnh `tx_stop` dừng phát dữ liệu. Sau khi dừng, carrier được kéo về trạng thái tắt bằng cách ghi `CCR1 = 0`.

Phản hồi:

```text
cmd_ok tx_stop
```

### 8.4. Lệnh `tx_carrier_on`

Lệnh `tx_carrier_on` bật chế độ carrier test. Trong chế độ này, firmware giữ `CCR1 = 84` để tạo carrier liên tục trên chân `PA8`. Lệnh này thường được dùng khi đo tần số carrier bằng oscilloscope.

Phản hồi:

```text
cmd_ok tx_carrier_on
```

### 8.5. Lệnh `tx_carrier_off`

Lệnh `tx_carrier_off` tắt chế độ carrier test.

Phản hồi:

```text
cmd_ok tx_carrier_off
```

### 8.6. Lệnh `tx_single`

Lệnh `tx_single` cho phép phát đúng một frame rồi tự dừng. Chế độ này phù hợp để kiểm tra dạng sóng frame trên oscilloscope hoặc debug quá trình nhận frame ở phía RX.

Phản hồi:

```text
cmd_ok tx_single
```

### 8.7. Lệnh `tx_status`

Lệnh `tx_status` in snapshot trạng thái TX hiện tại.

Dạng log:

```text
tx_status tx_enabled=<0|1> carrier_test=<0|1> tx_frames=<N> tx_frame_id=<N> bit_rate=100000 len=<N> payload=<HEX...> checksum=<XX> frame=<HEX...>
```

Log này giúp kiểm tra trạng thái bật/tắt TX, chế độ carrier test, số frame đã phát và nội dung frame hiện tại.

---

## 9. Cập nhật frame runtime an toàn

Khi payload được thay đổi bằng UART command, firmware không ghi trực tiếp lên buffer TX trong khi ISR có thể đang đọc dữ liệu. Để tránh tình trạng ISR đọc frame ở trạng thái chưa cập nhật hoàn chỉnh, firmware sử dụng cơ chế cập nhật an toàn như sau:

1. Build frame mới vào buffer tạm.
2. Vào critical section ngắn bằng `__disable_irq()`.
3. Copy frame mới vào buffer TX.
4. Reset chỉ số bit về đầu frame.
5. Thoát critical section bằng `__enable_irq()`.

Minh họa:

```text
Build frame mới vào buffer tạm
        ↓
__disable_irq()
        ↓
Copy frame mới vào buffer TX
        ↓
Reset bit index
        ↓
__enable_irq()
```

Mục tiêu của cách làm này là đảm bảo tính nhất quán của frame TX, đồng thời giữ thời gian khóa ngắt ngắn để không ảnh hưởng đến yêu cầu realtime của hệ thống.

---

## 10. Log TX qua UART

Các dòng log chính của TX gồm:

```text
role board_role=TX_ONLY
alive_tx tx_frames=<N> tx_frame_id=<N> bit_rate=100000 tx_enabled=<0|1> carrier_test=<0|1>
tx_frame tx_frame_id=<N> len=<N> payload=<HEX...> checksum=<XX> frame=<FULL_FRAME_HEX...>
adc_mv ...
dac_mv threshold=1650
rtc ...
```

Ý nghĩa các log:

| Log | Ý nghĩa |
| --- | --- |
| `role board_role=TX_ONLY` | Firmware đang chạy ở chế độ chỉ phát |
| `alive_tx ...` | Heartbeat định kỳ của TX |
| `tx_frame ...` | Snapshot frame TX hiện tại |
| `adc_mv ...` | Giá trị điện áp hệ thống đã scale theo mV |
| `dac_mv threshold=1650` | Ngưỡng DAC hiện tại |
| `rtc ...` | Thời gian RTC hiện tại |

Log được thiết kế theo dạng key-value để dễ đọc bằng terminal và dễ parse bằng GUI. Ví dụ:

```text
alive_tx tx_frames=120 tx_frame_id=120 bit_rate=100000 tx_enabled=1 carrier_test=0
```

---

## 11. Trạng thái runtime của TX

TX không sử dụng FSM phức tạp như RX, nhưng vẫn có các trạng thái runtime quan trọng:

| Trạng thái | Mô tả |
| --- | --- |
| `tx_enabled = 1` | Phát liên tục frame hiện tại |
| `tx_enabled = 0` | Không phát dữ liệu, carrier tắt |
| `carrier_test = 1` | Giữ carrier bật liên tục |
| `single_frame_mode = 1` | Phát một frame rồi tự dừng |

Các trạng thái này giúp firmware hỗ trợ nhiều kịch bản kiểm thử khác nhau, từ đo carrier cố định đến phát frame liên tục hoặc phát một frame đơn lẻ.

---

## 12. Luồng kiểm thử TX_ONLY

Khi kiểm thử chế độ `APP_BOARD_ROLE_TX_ONLY`, cần quan sát các tiêu chí sau:

1. `tx_frames` tăng đều theo thời gian khi TX được bật.
2. `tx_frame` hiển thị đúng payload mặc định hoặc payload vừa được cập nhật.
3. Command `tx_payload` phản hồi đúng độ dài và checksum.
4. Trên oscilloscope:

   * Có carrier 1 MHz trên chân `PA8`.
   * Dạng sóng OOK bật/tắt đúng theo bit `1` và `0`.
5. Khi dùng `tx_stop`, carrier phải tắt.
6. Khi dùng `tx_carrier_on`, carrier phải bật liên tục.
7. Không có thao tác UART logging bên trong ISR.

Bảng tiêu chí kiểm thử:

| Nội dung kiểm thử | Kết quả mong muốn |
| --- | --- |
| Carrier test | PA8 xuất carrier 1 MHz |
| `tx_start` | Frame được phát liên tục |
| `tx_stop` | Carrier bị tắt |
| `tx_single` | Chỉ phát một frame |
| `tx_payload` | Frame được build lại đúng payload và checksum |
| UART log | Log đúng format key-value |
| ISR | Không bị kéo dài bởi UART logging |

---

## 13. Kết luận

Luồng TX của OWC Project được thiết kế theo hướng tách biệt rõ ràng giữa khối phát thời gian thực và khối điều khiển nền. `TIM1` đảm nhiệm tạo carrier 1 MHz, trong khi `TIM2` cung cấp bit tick 100 kHz để phát từng bit OOK. Việc điều chế được thực hiện bằng cách thay đổi giá trị `TIM1 CCR1`, giúp bật hoặc tắt carrier tương ứng với bit dữ liệu.

Frame TX được build theo giao thức thống nhất trong `app_protocol`, bảo đảm định dạng dữ liệu giữa TX và RX là đồng nhất. Các command UART như `tx_payload`, `tx_start`, `tx_stop`, `tx_carrier_on`, `tx_carrier_off`, `tx_single` và `tx_status` được xử lý trong foreground loop, không xử lý trong ISR. Khi cập nhật payload runtime, firmware sử dụng critical section ngắn để tránh lỗi đọc/ghi đồng thời giữa main loop và ISR.

Nhìn chung, thiết kế TX đáp ứng các yêu cầu chính của hệ thống truyền thông quang OOK: duy trì timing ổn định, giữ ISR ngắn, hỗ trợ điều khiển runtime qua UART và cho phép debug dễ dàng bằng log cũng như oscilloscope.

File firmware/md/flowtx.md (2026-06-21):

```mermaid
flowchart TD
  A[main()] --> B[HAL_Init()]
  B --> C[SystemClock_Config()]
  C --> D[MX_GPIO_Init, MX_DMA_Init]
  D --> E[MX_TIM1_Init, MX_TIM2_Init]
  E --> F[MX_ADC1_Init, MX_USART2_UART_Init, MX_DAC_Init]
  F --> G[MX_TIM4_Init]
  G --> H[app_tasks_init()]
  H --> I[app_tasks_start()]
  I --> J[Start DAC threshold]
  J --> K[Start ADC monitor]
  K --> L{APP_BOARD_ROLE}
  L -->|TX_ONLY| M[vlc_tx_start()]
  L -->|RX_ONLY| N[vlc_rx_start()]
  L -->|TX_RX_LOOPBACK| O[vlc_tx_start() + vlc_rx_start()]
  M --> P[Start TIM2 interrupt]
  N --> P
  O --> P
  P --> Q[while(1) app_tasks_process()]

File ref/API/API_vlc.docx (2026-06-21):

Bảng API chính

Module | API | Chức năng | Khai báo | Định nghĩa
App tasks | app_tasks_init() | Khởi tạo UART, RTC, ADC, DAC, TX/RX | app_tasks.h (line 7) | app_tasks.c (line 878)
App tasks | app_tasks_start() | Start DAC/ADC/TX/RX/TIM2 theo board role | app_tasks.h (line 15) | app_tasks.c (line 904)
App tasks | app_tasks_process() | Main-loop task, UART command, logs, RX queue | app_tasks.h (line 17) | app_tasks.c (line 947)
App tasks | app_tasks_on_timer_period_elapsed() | TIM2 ISR dispatch theo board role | app_tasks.h (line 19) | app_tasks.c (line 927)
Protocol | app_protocol_get_expected_payload() | Lấy payload chuẩn 55 A5 3C C3 | app_protocol.h (line 14) | app_protocol.c (line 6)
Protocol | app_protocol_checksum() | Tính checksum LEN + sum(payload) | app_protocol.h (line 17) | app_protocol.c (line 17)
Protocol | app_protocol_get_expected_frame() | Build frame chuẩn để RX so sánh | app_protocol.h (line 19) | app_protocol.c (line 31)
Protocol | app_protocol_build_frame() | Build frame AA AA AA D5 LEN PAYLOAD CHECKSUM | app_protocol.h (line 21) | app_protocol.c (line 39)
TX | vlc_tx_init() | Init TX frame + TIM1 handle | vlc_tx.h (line 8) | vlc_tx.c (line 28)
TX | vlc_tx_start() | Start TIM1 PWM carrier | vlc_tx.h (line 10) | vlc_tx.c (line 43)
TX | vlc_tx_on_bit_tick() | Phát 1 bit OOK mỗi TIM2 tick | vlc_tx.h (line 12) | vlc_tx.c (line 55)
TX | vlc_tx_set_payload() | Đổi payload runtime, rebuild TX frame | vlc_tx.h (line 14) | vlc_tx.c (line 102)
TX | vlc_tx_set_enabled() | Bật/tắt truyền liên tục | vlc_tx.h (line 16) | vlc_tx.c (line 131)
TX | vlc_tx_set_carrier_test() | Bật/tắt carrier test mode | vlc_tx.h (line 18) | vlc_tx.c (line 147)
TX | vlc_tx_send_single_frame() | Gửi 1 frame rồi stop | vlc_tx.h (line 20) | vlc_tx.c (line 160)
TX | vlc_tx_get_frame_count() | Số frame TX đã hoàn tất | vlc_tx.h (line 30) | vlc_tx.c (line 195)
TX | vlc_tx_get_frame_snapshot() | Copy frame TX hiện tại cho log/status | vlc_tx.h (line 32) | vlc_tx.c (line 201)
RX | vlc_rx_init() | Init RX queue, stats, FSM | vlc_rx.h (line 42) | vlc_rx.c (line 67)
RX | vlc_rx_start() | Start TIM4 edge counter | vlc_rx.h (line 44) | vlc_rx.c (line 90)
RX | vlc_rx_on_bit_tick() | Đọc TIM4 delta, tạo raw bit, gọi FSM | vlc_rx.h (line 46) | vlc_rx.c (line 105)
RX | vlc_rx_pop_frame() | Pop valid RX frame + frame id | vlc_rx.h (line 50) | vlc_rx.c (line 216)
RX | vlc_rx_get_stats() | Lấy RX counters/debug values | vlc_rx.h (line 52) | vlc_rx.c (line 231)
RX Sync | rx_sync_init() | Reset FSM đồng bộ frame | rx_sync.h (line 42) | rx_sync.c (line 60)
RX Sync | rx_sync_on_tick() | FSM xử lý 1 raw bit | rx_sync.h (line 44) | rx_sync.c (line 73)
RX Sync | rx_sync_get_state() | Lấy state hiện tại của FSM | rx_sync.h (line 46) | rx_sync.c (line 66)
UART | bsp_uart_init() | Bind UART handle | bsp_uart.h (line 9) | bsp_uart.c (line 7)
UART | bsp_uart_printf() | In log UART blocking | bsp_uart.h (line 11) | bsp_uart.c (line 13)
UART | bsp_uart_read_byte() | Poll 1 byte command UART | bsp_uart.h (line 13) | bsp_uart.c (line 42)
ADC | bsp_adc_monitor_init() | Init ADC monitor | bsp_adc_monitor.h (line 21) | bsp_adc_monitor.c (line 15)
ADC | bsp_adc_monitor_start() | Start ADC DMA/monitor | bsp_adc_monitor.h (line 23) | bsp_adc_monitor.c (line 21)
ADC | bsp_adc_monitor_get_voltages() | Lấy điện áp đã scale mV | bsp_adc_monitor.h (line 27) | bsp_adc_monitor.c (line 59)
DAC | bsp_dac_threshold_init() | Init DAC threshold | bsp_dac_threshold.h (line 8) | bsp_dac_threshold.c (line 8)
DAC | bsp_dac_threshold_set_mv() | Set DAC threshold mV | bsp_dac_threshold.h (line 10) | bsp_dac_threshold.c (line 15)
DAC | bsp_dac_threshold_get_mv() | Đọc threshold hiện tại | bsp_dac_threshold.h (line 12) | bsp_dac_threshold.c (line 37)
RTC | bsp_rtc_init() | Init LSE RTC + backup magic | bsp_rtc.h (line 9) | bsp_rtc.c (line 173)
RTC | bsp_rtc_set_datetime() | Set RTC date/time | bsp_rtc.h (line 14) | bsp_rtc.c (line 124)
RTC | bsp_rtc_get_datetime_string() | Format YYYY-MM-DD HH:MM:SS | bsp_rtc.h (line 12) | bsp_rtc.c (line 227)
RTC | bsp_rtc_print_log() | In dòng rtc ... | bsp_rtc.h (line 13) | bsp_rtc.c (line 259)
RTC | bsp_rtc_print_backup_log() | In dòng rtc_bkp ... | bsp_rtc.h (line 17) | bsp_rtc.c (line 272)

Bảng define cấu hình chính

Nhóm | Define | Giá trị | Vị trí
Bit rate | APP_BIT_RATE_HZ | 100000U | app_config.h (line 6)
TIM2 | APP_TIM2_TICK_HZ | 100000U | app_config.h (line 7)
TIM2 | APP_TIM2_ARR_100KHZ | 839U | app_config.h (line 8)
TIM1 PWM | APP_TIM1_PWM_PERIOD | 167U | app_config.h (line 10)
OOK | APP_TIM1_CARRIER_CCR_ON | 84U | app_config.h (line 11)
OOK | APP_TIM1_CARRIER_CCR_OFF | 0U | app_config.h (line 12)
RX | APP_RX_EDGE_THRESHOLD | 6U | app_config.h (line 15)
Frame | APP_FRAME_PREAMBLE_BYTE | 0xAAU | app_config.h (line 18)
Frame | APP_FRAME_PREAMBLE_BYTES | 3U | app_config.h (line 19)
Frame | APP_FRAME_SYNC_BYTE | 0xD5U | app_config.h (line 20)
Frame | APP_MAX_PAYLOAD_LEN | 32U | app_config.h (line 21)
Queue | APP_RX_QUEUE_DEPTH | 32U | app_config.h (line 22)
Queue | APP_RX_ERROR_EVENT_QUEUE_DEPTH | 16U | app_config.h (line 23)
Role | APP_BOARD_ROLE_TX_ONLY | 0U | app_config.h (line 25)
Role | APP_BOARD_ROLE_RX_ONLY | 1U | app_config.h (line 26)
Role | APP_BOARD_ROLE_TX_RX_LOOPBACK | 2U | app_config.h (line 27)
Role | APP_BOARD_ROLE | APP_BOARD_ROLE_TX_ONLY | app_config.h (line 29)
DAC | APP_DAC_DEFAULT_THRESHOLD_MV | 1650U | app_config.h (line 35)
ADC | APP_ADC_CHANNEL_COUNT | 7U | app_config.h (line 37)
ADC | APP_ADC_VREF_MV | 3300U | app_config.h (line 38)
Log | APP_LOG_PERIOD_MS | 1000U | app_config.h (line 40)
Error log | APP_ERR_LOG_MAX_PER_PERIOD | 5U | app_config.h (line 41)
Error bits | APP_ERR_BITS_MAX_PER_PERIOD | 1U | app_config.h (line 42)
RTC | APP_RTC_ENABLE | 1U | app_config.h (line 45)
RTC | APP_RTC_USE_LSE | 1U | app_config.h (line 46)
RTC | APP_RTC_MAGIC | 0x32F4U | app_config.h (line 47)
RTC | APP_RTC_DEFAULT_YEAR | 2026U | app_config.h (line 48)
RTC | APP_RTC_LOG_ENABLE | 1U | app_config.h (line 54)
RX sync error | RX_SYNC_ERROR_SYNC | 1U | rx_sync.h (line 36)
RX sync error | RX_SYNC_ERROR_LENGTH | 2U | rx_sync.h (line 37)
RX sync error | RX_SYNC_ERROR_PREAMBLE | 3U | rx_sync.h (line 38)
Board pin | PIN_RX_OUT_D_Pin | GPIO_PIN_6 | board_pins.h (line 7)
Board pin | PIN_TX_READY_Pin | GPIO_PIN_13 | board_pins.h (line 10)
Board pin | PIN_RX_READY_Pin | GPIO_PIN_15 | board_pins.h (line 13)
HAL | HAL_RTC_MODULE_ENABLED | enabled | stm32f4xx_hal_conf.h (line 61)
HAL | LSE_VALUE | 32768U | stm32f4xx_hal_conf.h (line 127)
HAL | LSE_STARTUP_TIMEOUT | 5000U | stm32f4xx_hal_conf.h (line 131)

Struct/Enum quan trọng

Tên | Loại | Ý nghĩa | Vị trí
app_frame_t | struct | Frame decoded: length, payload, checksum | app_protocol.h (line 7)
rx_sync_state_t | enum | Các state FSM RX sync | rx_sync.h (line 7)
rx_sync_result_t | struct | Kết quả mỗi tick RX FSM | rx_sync.h (line 18)
vlc_rx_stats_t | struct | RX counters/debug stats | vlc_rx.h (line 8)
vlc_rx_error_event_t | struct | Deferred RX error event | vlc_rx.h (line 23)
bsp_adc_voltages_t | struct | Các điện áp ADC đã scale mV | bsp_adc_monitor.h (line 7)

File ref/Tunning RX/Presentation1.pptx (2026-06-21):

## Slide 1

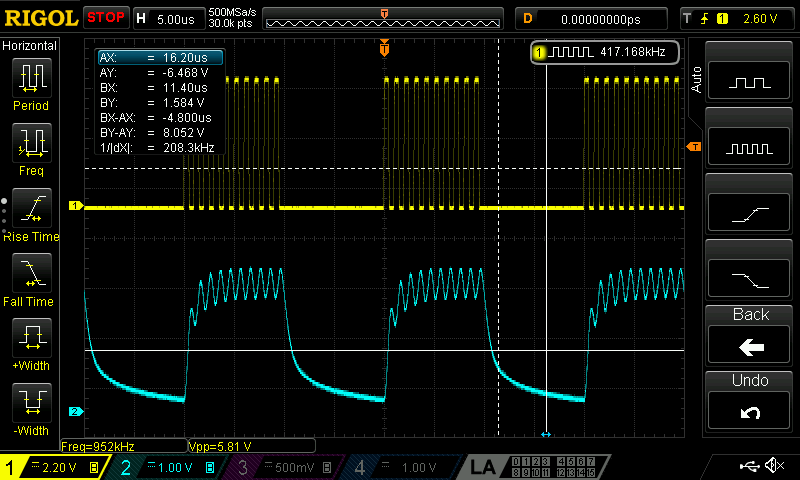
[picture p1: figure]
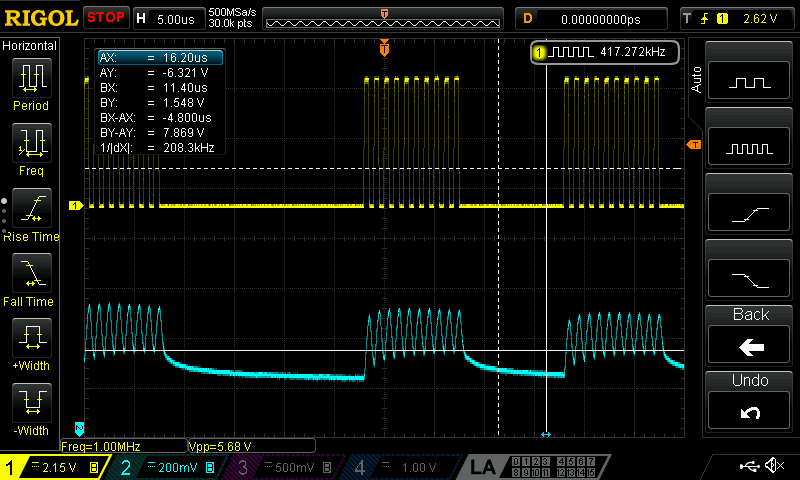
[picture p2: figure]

TX

TX

RX

Rf = 470KOhm

RX

Rf = 100KOhm

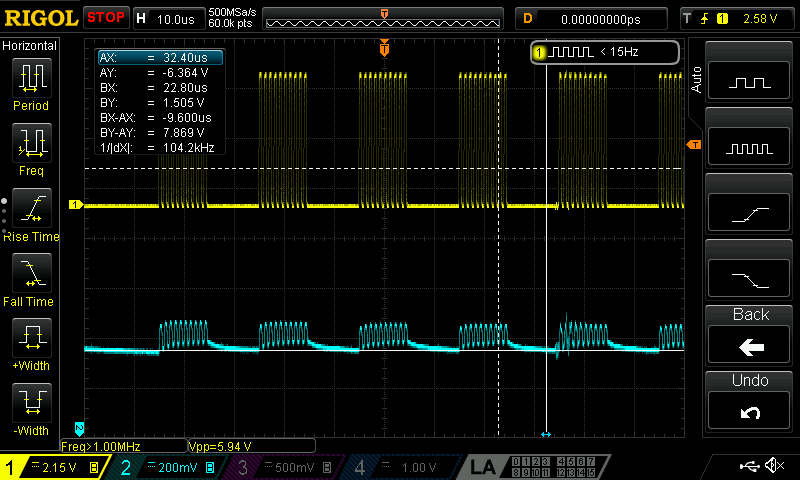
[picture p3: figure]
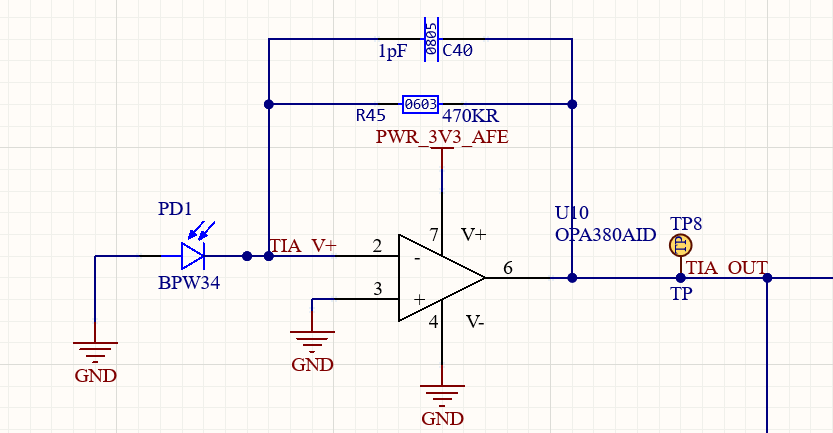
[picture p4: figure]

TX

RX

Rf = 36KOhm

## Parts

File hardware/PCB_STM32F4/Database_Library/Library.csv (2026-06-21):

LIBRARYREFERENCE | COMMENT | POWER RATE | SIZE | SHEETPART | DESIGNATOR | DESCRIPTION
AMS1117 | * |  |  | * | U?
BAT54C | * |  |  | * | U?
BUTTON_SMD | * |  |  | * | BUTT?
CAPACITOR | * |  | 0805 | * | C?
CAPACITOR ALU | * |  |  | * | C?
CAPACITOR TATA | * |  |  | * | C?
CH340G | * |  |  | * | U?
CON-2 | * |  |  | * | J?
CON-3 | * |  |  | * | K?
CON-4 | * |  |  | * | C?
CON-6 | * |  |  | * | J?
CON-8 | * |  |  | * | K?
DIODE | * |  |  | * | D?
DIODE_ZE | * |  |  | * | U?
Dual_BAT | * |  |  | * | BAT?
ESP32-WROOM-32E | * |  |  | * | U?
FB | * |  |  | * | FB?
HOLDER BAT | * |  |  | * | VBAT?
ICL7662CBA | * |  |  | * | U?
INA128UA | * |  |  | * | U?
INDUCTOR | * |  |  | * | L?
JACK 2.1 | * |  |  | * | J?
JACK_3.5 | * |  |  | * | J?
LED_BLUE | * |  |  | * | D?
LED_RED | * |  |  | * | D?
LM393DT | * |  |  | * | U?
OPA188AID | * |  |  | * | U?
OPA2134UA | * |  |  | * | U?
PJ-327A-5P | * |  |  | * | K?
P_MOS | * |  |  | * | Q?
RESISTOR | * | * | 0603 | * | R?
RESISTOR TH | * |  | TH | * | R?
RT9013 | * |  |  | * | U?
SB | * |  |  | * | SB?
SLIDE-SW | * |  |  | * | SW?
SMAJ12 | * |  |  | * | D?
SMAJ5.0 | * |  |  | * | D?
SS34 | * |  |  | * | D?
STM32F103C8T6 | * |  |  | * | U?
STM32F407VET6 | * |  |  | * | U?
TPS5430DDA | * |  |  | * | U?
TPS54331DR | * |  |  | * | U?
Test_point | * |  |  | * | TP?
USB_C | * |  |  | *
VRES | * |  |  | * | VR?
XTAL 8MHZ | * |  |  | * | *
XTAL_12MHZ | * |  |  | * | Y?
XTAL_2 | * |  |  | * | Y?
XTAL_4 | * |  |  | * | Y?

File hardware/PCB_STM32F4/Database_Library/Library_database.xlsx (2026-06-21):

Design Item ID | Comment | Description | Type | Power Rate | Value | Tolerance | Footprint Type | Size | Supplier | Supplier Part Number | Supplier Link | Library Ref | Library Path | Footprint Ref | Footprint Path
DB-0001 | 680R | RESISTOR SMD 680R OHM 5% 100mW 0603 | RESISTOR | 100mW | 680R | 5% | SMD | 0603 | THEGIOIIC | Điện Trở 680 Ohm 0603 5% | https://www.thegioiic.com/dien-tro-680-ohm-0603-5- | RESISTOR | .\Database_Library\Library.SchLib | RESC 0603(1608) SMD | .\Database_Library\Library.PcbLib
DB-0002 | TPS5430DDAR | TPS543x 3A, Wide Input Range, Step-Down Converter | IC | N/A | N/A | N/A | SMD | 8-SOIC | THEGIOIIC | TPS5430DDAR IC Điều Chỉnh Giảm Áp 3A 8-SOIC | https://www.thegioiic.com/tps5430ddar-ic-dieu-chinh-giam-ap-3a-8-soic | TPS5430DDA | .\Database_Library\Library.SchLib | 8-SOIC | .\Database_Library\Library.PcbLib
DB-0003 | 10KR | RESISTOR SMD 10KR OHM 1% 100mW 0603 | RESISTOR | 100mW | 10KR | 1% | SMD | 0603 | THEGIOIIC | Điện Trở 10 KOhm 0603 1% | https://www.thegioiic.com/dien-tro-10-kohm-0603-1- | RESISTOR | .\Database_Library\Library.SchLib | RESC 0603(1608) SMD | .\Database_Library\Library.PcbLib
DB-0004 | 3.24KR | RESISTOR SMD 3.24KR OHM 1% 100mW 0604 | RESISTOR | 100mW | 3.24KR | 1% | SMD | 0603 |  |  |  | RESISTOR | .\Database_Library\Library.SchLib | RESC 0603(1608) SMD | .\Database_Library\Library.PcbLib
DB-0005 | 240R | RESISTOR SMD 240R OHM 1% 100mW 0805 | RESISTOR | 120mW | 240R | 1% | SMD | 0805 | THEGIOIIC | Điện Trở 240 Ohm 0805 1% | https://www.thegioiic.com/dien-tro-240-ohm-0805-1- | RESISTOR | .\Database_Library\Library.SchLib | RESC 0805 SMD | .\Database_Library\Library.PcbLib
DB-0006 | 3KR | RESISTOR SMD 3KR OHM 1% 100mW 0805 | RESISTOR | 120mW | 3KR | 1% | SMD | 0805 | THEGIOIIC | Điện Trở 3K Ohm 0805 1% | https://www.thegioiic.com/dien-tro-3-kohm-0805-1- | RESISTOR | .\Database_Library\Library.SchLib | RESC 0805 SMD | .\Database_Library\Library.PcbLib
DB-0007 | 4.7uF | CAPACITOR SMD 4.7uF 50V 10% 0805 | CAPACITOR | N/A | 4.7uF | 10% | SMD | 0805 | THEGIOIIC | Tụ Gốm 0805 4.7uF 50V | https://www.thegioiic.com/tu-gom-0805-4-7uf-50v | CAPACITOR | .\Database_Library\Library.SchLib | CAPCER 0805 SMD | .\Database_Library\Library.PcbLib
DB-0008 | 100KR | RESISTOR SMD 100KR OHM 1% 100mW 0603 | RESISTOR | 100mW | 100KR | 1% | SMD | 0603 | THEGIOIIC | Điện Trở 100 KOhm 0603 1% | https://www.thegioiic.com/dien-tro-100-kohm-0603-1- | RESISTOR | .\Database_Library\Library.SchLib | RESC 0603(1608) SMD | .\Database_Library\Library.PcbLib
DB-0009 | 470KR | RESISTOR SMD 470KR OHM 1% 100mW 0603 | RESISTOR | 100mW | 470KR | 1% | SMD | 0603 | THEGIOIIC | Điện Trở 470 KOhm 0603 1% | https://www.thegioiic.com/dien-tro-470-kohm-0603-1- | RESISTOR | .\Database_Library\Library.SchLib | RESC 0603(1608) SMD | .\Database_Library\Library.PcbLib
DB-0010 | 0.01uF | CAPACITOR SMD 0.01uF 50V 10% 0805 | CAPACITOR | N/A | 0.01uF | 10% | SMD | 0805 | THEGIOIIC | Tụ Gốm 0805 410nF 50V | https://www.thegioiic.com/tu-gom-0805-10nf-50v | CAPACITOR | .\Database_Library\Library.SchLib | CAPCER 0805 SMD | .\Database_Library\Library.PcbLib
DB-0011 | 22uH | INDUCTOR SMD 22uH 1280-220 6.3A | INDUCTOR | N/A | 22uH | 20% | SMD | 1280 | THEGIOIIC | CDRH127 Cuộn Cảm Dán SMD 1280-220 22uH 6.3A | https://www.thegioiic.com/cdrh127-cuon-cam-dan-smd-1280-220-22uh-6-3a | INDUCTOR | .\Database_Library\Library.SchLib | INDUCTOR 1280 SMD | .\Database_Library\Library.PcbLib
DB-0012 | 1N5408 | Surface Mount General Purpose Silicon Rectifiers 3A 1KV | DIODE | N/A | 3A-1KV | N/A | SMD | SMA | THEGIOIIC | 1N5408 S3M SMA Diode Chỉnh Lưu 3A 1KV | https://www.thegioiic.com/1n5408-s3m-sma-diode-chinh-luu-3a-1kv | DIODE | .\Database_Library\Library.SchLib | SMA | .\Database_Library\Library.PcbLib
DB-0013 | 220uF | CAPACITOR ALU SMD 220uF 16V 10% 6377 | CAPACITOR ALU | N/A | 220uF | N/A | SMD | 6377 | THEGIOIIC | Tụ Nhôm SMD 220uF 16V 6.3x7.7mm | https://www.thegioiic.com/tu-nhom-smd-220uf-16v-6-3x7-7mm | CAPACITOR ALU | .\Database_Library\Library.SchLib | CAP ALU 6377 | .\Database_Library\Library.PcbLib
DB-0014 | OPA188AID | Zero-Drift Amplifier 1 Circuit Rail-to-Rail 8-SOIC | IC | N/A | N/A | N/A | SMD | 8-SOIC | DIGIKEY | OPA188AID | https://www.digikey.com/en/products/detail/texas-instruments/OPA188AID/4146941 | OPA188AID | .\Database_Library\Library.SchLib | 8-SOIC-OPA | .\Database_Library\Library.PcbLib
DB-0015 | INA128UA | Instrumentation Amplifier 1 Circuit 8-SOIC | IC | N/A | N/A | N/A | SMD | 8-SOIC | DIGIKEY | INA128UA | https://www.digikey.com/en/products/detail/texas-instruments/INA128UA/300997 | INA128UA | .\Database_Library\Library.SchLib | 8-SOIC-OPA | .\Database_Library\Library.PcbLib
DB-0016 | 300KR | RESISTOR SMD 300KR OHM 5% 125mW 0805 | RESISTOR | 125mW | 300KR | 5% | SMD | 0805 | THEGIOIIC | Điện Trở 300 KOhm 0805 5% | https://www.thegioiic.com/dien-tro-300-kohm-0805-5- | RESISTOR | .\Database_Library\Library.SchLib | RESC 0805 SMD | .\Database_Library\Library.PcbLib
DB-0017 | 0.1uF | CAPACITOR SMD 0.1uF 50V 10% 0603 | CAPACITOR | N/A | 0.1uF | 10% | SMD | 0603 | THEGIOIIC | Tụ Gốm 0603 100nF (0.1uF) 25V | https://www.thegioiic.com/tu-gom-0603-100nf-0-1uf-25v | CAPACITOR | .\Database_Library\Library.SchLib | CAPCER 0805 SMD | .\Database_Library\Library.PcbLib
DB-0018 | 10uF | CAPACITOR SMD 10uF 25V 10% 0805 | CAPACITOR | N/A | 10uF | 10% | SMD | 0805 | THEGIOIIC | Tụ Gốm 0805 10uF 25V | https://www.thegioiic.com/tu-gom-0805-10uf-25v | CAPACITOR | .\Database_Library\Library.SchLib | CAPCER 0805 SMD | .\Database_Library\Library.PcbLib
DB-0019 | LED_BLUE | Size 2x1.2mm, điện áp 1.8-2.6VDC | LED | N/A | N/A | N/A | SMD | 0805 | THEGIOIIC | LED Xanh Dương 0805 Dán SMD Trong Suốt | https://www.thegioiic.com/led-xanh-duong-0805-dan-smd-trong-suot | LED_BLUE | .\Database_Library\Library.SchLib | LED 0805 SMD | .\Database_Library\Library.PcbLib
DB-0020 | LED_RED | Size 2x1.2mm, điện áp 1.8-2.6VDC | LED | N/A | N/A | N/A | SMD | 0806 | THEGIOIIC | LED Đỏ 0805 Dán SMD Trong Suốt Harvatek | https://www.thegioiic.com/led-do-0805-dan-smd-trong-suot-harvatek | LED_RED | .\Database_Library\Library.SchLib | LED 0805 SMD | .\Database_Library\Library.PcbLib
DB-0021 | SMAJ5.0 | TVS DIODE 5VWM 9.2VC SMA | DIODE | N/A | 3A-1KV | N/A | SMD | SMA | DIGIKEY | TVS DIODE 5VWM 9.2VC SMA | https://www.digikey.com/en/products/detail/diodes-incorporated/smaj5-0a-13/278666 | SMAJ5.0 | .\Database_Library\Library.SchLib | DO-214AC | .\Database_Library\Library.PcbLib
DB-0022 | 270R | RESISTOR SMD 270R OHM 5% 125mW 0805 | RESISTOR | 125mW | 270R | 5% | SMD | 0805 | THEGIOIIC | Điện Trở 270 Ohm 0805 5% | https://www.thegioiic.com/dien-tro-270-ohm-0805-5- | RESISTOR | .\Database_Library\Library.SchLib | RESC 0805 SMD | .\Database_Library\Library.PcbLib
DB-0023 | 5.6KR | RESISTOR SMD 5.6KR OHM 1% 125mW 0805 | RESISTOR | 125mW | 5.6KR | 1% | SMD | 0805 | THEGIOIIC | Điện Trở 5.6 KOhm 0805 1% | https://www.thegioiic.com/dien-tro-5-6-kohm-0805-1- | RESISTOR | .\Database_Library\Library.SchLib | RESC 0805 SMD | .\Database_Library\Library.PcbLib
DB-0024 | 300R | RESISTOR SMD 300R OHM 1% 125mW 0603 | RESISTOR | 125mW | 300R | 1% | SMD | 0603 | THEGIOIIC | Điện Trở 300 Ohm 0603 1% | https://www.thegioiic.com/dien-tro-300-ohm-0603-1- | RESISTOR | .\Database_Library\Library.SchLib | RESC 0603(1608) SMD | .\Database_Library\Library.PcbLib
DB-0025 | 1.6MR | RESISTOR SMD 1.6MR OHM 5% 125mW 0805 | RESISTOR | 125mW | 1.6MR | 5% | SMD | 0805 | THEGIOIIC | Điện Trở 1.6 KOhm 0805 5% | https://www.thegioiic.com/dien-tro-1-6-kohm-0805-5- | RESISTOR | .\Database_Library\Library.SchLib | RESC 0805 SMD | .\Database_Library\Library.PcbLib
DB-0026 | VR_10KR | EVM3E-103 Biến Trở 10 KOhm Nút Áo SMD 0.15W | VRES | 0.15W | VR_10KR | 20% | SMD | EVM3E | THEGIOIIC | EVM3E-103 Biến Trở 10 KOhm Nút Áo SMD 0.15W | https://www.thegioiic.com/evm3e-103-bien-tro-10-kohm-nut-ao-smd-0-15w | VRES | .\Database_Library\Library.SchLib | EVM3E | .\Database_Library\Library.PcbLib
DB-0027 | 12KR | RESISTOR SMD 12KR OHM 1% 100mW 0603 | RESISTOR | 100mW | 12KR | 1% | SMD | 0603 | THEGIOIIC | Điện Trở 12 KOhm 0603 1% | https://www.thegioiic.com/dien-tro-12-kohm-0603-1- | RESISTOR | .\Database_Library\Library.SchLib | RESC 0603(1608) SMD | .\Database_Library\Library.PcbLib
DB-0028 | 510R | RESISTOR SMD 510R OHM 1% 100mW 0603 | RESISTOR | 100mW | 500R | 1% | SMD | 0603 | THEGIOIIC | Điện Trở 510 Ohm 0603 1% | https://www.thegioiic.com/dien-tro-510-ohm-0603-1- | RESISTOR | .\Database_Library\Library.SchLib | RESC 0603(1608) SMD | .\Database_Library\Library.PcbLib
DB-0029 | OPA2134UA | IC AUDIO 2 CIRCUIT 8SOIC | IC | N/A | N/A | N/A | SMD+NH30:O30 | 8-SOIC | DIGIKEY | IC AUDIO 2 CIRCUIT 8SOIC | https://www.digikey.com/en/products/detail/texas-instruments/OPA2134UA | OPA2134UA | .\Database_Library\Library.SchLib | 8-SOIC-OPA | .\Database_Library\Library.PcbLib
DB-0030 | AMS1117-ADJ | AMS1117-3.3V IC Ổn Áp 3.3V 1A SOT-223 | IC | N/A | N/A | N/A | SMD | SOT-223 | THEGIOIIC | AMS1117-3.3V IC Ổn Áp 3.3V 1A SOT-223 | https://www.thegioiic.com/ams1117-3-3v-ic-on-ap-3-3v-1a-sot-223 | AMS1117 | .\Database_Library\Library.SchLib | SOT-223 | .\Database_Library\Library.PcbLib
DB-0031 | Dual_Battery_Case | Dual_Battery_Case_18650 | Case | N/A | N/A | N/A | TFT |  |  |  | https://www.thegioiic.com/de-pin-2x18650-han-pcb | Dual_BAT | .\Database_Library\Library.SchLib | Dual_BAT_PCB | .\Database_Library\Library.PcbLib
DB-0032 | SS34 | SS34 SMC Diode Schottky 3A | DIODE | N/A | SS34 | N/A | SMD | SMA | THEGIOIIC | TWGMC SS34 SMA Diode Schottky 3A | https://www.thegioiic.com/twgmc-ss34-sma-diode-schottky-3a | SS34 | .\Database_Library\Library.SchLib | DO-214AC | .\Database_Library\Library.PcbLib
DB-0033 | 15uH | INDUCTOR SMD 15uH 1280-150 7.1A | INDUCTOR | N/A | 15uH | 20% | SMD | 1280 | THEGIOIIC | Cuộn Cảm Dán SMD CDRH127 1280-150 15uH 7.1A | https://www.thegioiic.com/cuon-cam-dan-smd-cdrh127-1280-150-15uh-7-1a | INDUCTOR | .\Database_Library\Library.SchLib | INDUCTOR 1280 SMD | .\Database_Library\Library.PcbLib
DB-0034 | TEST_POINT |  |  | N/A | N/A | N/A | PAD | PAD |  |  |  | Test_point | .\Database_Library\Library.SchLib | Test_point | .\Database_Library\Library.PcbLib
DB-0035 | TPS54331DR | TPS54331DR IC Điều Chỉnh Giảm Áp 3A 8-SOIC | IC | N/A | N/A | N/A | SMD | 8-SOIC | THEGIOIIC | TPS54331DR IC Điều Chỉnh Giảm Áp 3A 8-SOIC | https://www.thegioiic.com/tps54331dr-ic-dieu-chinh-giam-ap-3a-8-soic | TPS54331DR | .\Database_Library\Library.SchLib | 8-SOIC-OPA | .\Database_Library\Library.PcbLib
DB-0036 | 47pF | CAPACITOR SMD 47pF 50V 10% 0805 | CAPACITOR | N/A | 47pF | 10% | SMD | 0805 | THEGIOIIC | Tụ Gốm 0805 47pF 50V | https://www.thegioiic.com/tu-gom-0805-47pf-50v | CAPACITOR | .\Database_Library\Library.SchLib | CAPCER 0805 SMD | .\Database_Library\Library.PcbLib
DB-0037 | 1nF | CAPACITOR SMD 1nF 50V 10% 0805 | CAPACITOR | N/A | 1nF | 10% | SMD | 0805 | THEGIOIIC | Tụ Gốm 0805 1nF 50V | https://www.thegioiic.com/tu-gom-0805-1nf-50v | CAPACITOR | .\Database_Library\Library.SchLib | CAPCER 0805 SMD | .\Database_Library\Library.PcbLib
DB-0038 | 27KR | RESISTOR SMD 27KR OHM 1% 100mW 0603 | RESISTOR | 100mW | 27KR | 1% | SMD | 0603 | THEGIOIIC | Điện Trở 27 KOhm 0603 1% |  | RESISTOR | .\Database_Library\Library.SchLib | RESC 0603(1608) SMD | .\Database_Library\Library.PcbLib
DB-0039 | 2.4KR | RESISTOR SMD 2.4KR OHM 5% 100mW 0805 | RESISTOR | 100mW | 2.4KR | 5% | SMD | 0805 | THEGIOIIC | Điện Trở 2.4 KOhm 0805 5% | https://www.thegioiic.com/dien-tro-2-4-kohm-0805-5- | RESISTOR | .\Database_Library\Library.SchLib | CAPCER 0805 SMD | .\Database_Library\Library.PcbLib
DB-0040 | 0R | RESISTOR SMD 0KR OHM 1% 100mW 0603 | RESISTOR | 100mW | 0KR | 1% | SMD | 0603 | THEGIOIIC | Điện Trở 0 Ohm 0603 1% | https://www.thegioiic.com/dien-tro-0-ohm-0603-1- | RESISTOR | .\Database_Library\Library.SchLib | RESC 0603(1608) SMD | .\Database_Library\Library.PcbLib
DB-0041 | AO3407A | AO3407A MOSFET Kênh P 30V 4.3A SOT-23-3 | P_MOSFET | N/A | 30V 4.3A | N/A | SMD | SOT23-3 | THEGIOIIC | AO3407A MOSFET Kênh P 30V 4.3A SOT-23-3 | https://www.thegioiic.com/ao3407a-mosfet-kenh-p-30v-4-3a-sot-23-3 | P_MOS | .\Database_Library\Library.SchLib | SOT23-3 | .\Database_Library\Library.PcbLib
DB-0042 | BZT52H | BZT52H-C12 Diode Zener 12V 375mW SOD-123F | DIODE_ZE | 375mW | 12V | 5% | SMD | SOD-123F | THEGIOIIC | BZT52H-C12 Diode Zener 12V 375mW SOD-123F | https://www.thegioiic.com/bzt52c5v1-diode-zener-5-1v-500mw | DIODE_ZE | .\Database_Library\Library.SchLib | SOD-123F | .\Database_Library\Library.PcbLib
DB-0043 | 10uH | INDUCTOR SMD 10uH 1280-100 7.1A | INDUCTOR | N/A | 10uH | 20% | SMD | 1280 | THEGIOIIC | Cuộn Cảm Dán SMD CDRH127 1280-100 10uH 7.8A | https://www.thegioiic.com/cuon-cam-dan-smd-cdrh127-1280-100-10uh-7-8a | INDUCTOR | .\Database_Library\Library.SchLib | INDUCTOR 1280 SMD | .\Database_Library\Library.PcbLib
DB-0044 | 330uF | CAPACITOR ALU SMD 220uF 6.3V 20% 6377 | CAPACITOR ALU | N/A | 330uF | 20% | SMD | 6377 | THEGIOIIC | Tụ Nhôm SMD 330uF 6.3V 6.3x7.7mm | https://www.thegioiic.com/tu-nhom-smd-330uf-6-3v-6-3x7-7mm | CAPACITOR ALU | .\Database_Library\Library.SchLib | CAP ALU 6377 | .\Database_Library\Library.PcbLib
DB-0045 | STM32F103C8T6 | STM32F103C8T6, 32-Bit ARM Cortex M3 Microcontroller, 72MHz, 64KB FLASH, 48-LQFP STM32F103C8T6, 32-Bit ARM Cortex M3 Microcontroller, 72MHz, 64KB FLASH, 48-LQFP | IC | N/A | N/A | N/A | SMD | LQFP48 | THEGIOIIC | STM32F103C8T6, 32-Bit ARM Cortex M3 Microcontroller, 72MHz, 64KB FLASH, 48-LQFP STM32F103C8T6, 32-Bit ARM Cortex M3 Microcontroller, 72MHz, 64KB FLASH, 48-LQFP | https://www.thegioiic.com/stm32f103c8t6-32-bit-arm-cortex-m3-microcontroller-72mhz-64kb-flash-48-lqfp | STM32F103C8T6 | .\Database_Library\Library.SchLib | LQFP48 | .\Database_Library\Library.PcbLib
DB-0046 | Thạch Anh 8Mhz | Thạch Anh 8Mhz 2 Chân SMD HC49-S | XTAL | N/A | 8MHz | N/A | SMD | HC49-S | THEGIOIIC | Thạch Anh 8Mhz 2 Chân SMD HC49-S | https://www.thegioiic.com/thach-anh-8mhz-2-chan-smd-hc49-s | XTAL_2 | .\Database_Library\Library.SchLib | HC49-S | .\Database_Library\Library.PcbLib
DB-0047 | 22pF | CAPACITOR SMD 22pF 50V 10% 0805 | CAPACITOR | N/A | 22pF | 10% | SMD | 0805 | THEGIOIIC | Tụ Gốm 0805 22pF 50V | https://www.thegioiic.com/tu-gom-0805-22pf-50v | CAPACITOR | .\Database_Library\Library.SchLib | CAPCER 0805 SMD | .\Database_Library\Library.PcbLib
DB-0048 | 330R | RESISTOR SMD 330R OHM 1% 125mW 0805 | RESISTOR | 125mW | 330R | 1% | SMD | 0806 | THEGIOIIC | Điện Trở 330 Ohm 0805 1% | https://www.thegioiic.com/dien-tro-330-ohm-0805-1- | RESISTOR | .\Database_Library\Library.SchLib | RESC 0805 SMD | .\Database_Library\Library.PcbLib
DB-0049 | CONNECTOR_4 | Hàng Rào Đực Đơn 2.54mm 40 Chân 1 Hàng Cao 11.2mm Xuyên Lỗ | CONNECTOR | N/A | CON-4 | N/A | TFT | TFT | THEGIOIIC | Hàng Rào Đực Đơn 2.54mm 40 Chân 1 Hàng Cao 11.2mm Xuyên Lỗ | https://www.thegioiic.com/hang-rao-duc-don-2-54mm-40-chan-1-hang-cao-11-2mm-xuyen-lo | CON-4 | .\Database_Library\Library.SchLib | CON-4 | .\Database_Library\Library.PcbLib
DB-0050 | ESP32-WROOM-32E-N4 | ESP32-WROOM-32E-N4 Module WiFi Bluetooth 4MB Flash 2.4GHz | IC | N/A | N/A | N/A | SMD | ESP32-WROOM-32E | THEGIOIIC | ESP32-WROOM-32E-N4 Module WiFi Bluetooth 4MB Flash 2.4GHz | https://www.thegioiic.com/esp32-wroom-32e-n4-module-wifi-bluetooth-4mb-flash-2-4ghz | ESP32-WROOM-32E | .\Database_Library\Library.SchLib | ESP32-WROOM-32E | .\Database_Library\Library.PcbLib
DB-0051 | BUTTON | Nút Nhấn 4x4mm Cao 1.5mm 4 Chân SMD Chống Nước | BUTTON | N/A | N/A | N/A | SMD | BUTTON_SMD | THEGIOIIC | Nút Nhấn 4x4mm Cao 1.5mm 4 Chân SMD Chống Nước | https://www.thegioiic.com/nut-nhan-4x4mm-cao-1-5mm-4-chan-smd-chong-nuoc | BUTTON_SMD | .\Database_Library\Library.SchLib | BUTTON_SMD | .\Database_Library\Library.PcbLib
DB-0052 | ICL7662CBA | IC Dán ICL7662 SOP-8 (SMD) (ICL7662CBA) | IC | N/A | N/A | N/A | SMD | 8-SOIC | Điện tử Minh Nguyên | IC Dán ICL7662 SOP-8 (SMD) (ICL7662CBA) | https://chipn24.com/sop-ic-dan-icl7662-sop-8-smd-icl7662cba-id9015.html#prettyPhoto | ICL7662CBA | .\Database_Library\Library.SchLib | 8-SOIC-OPA | .\Database_Library\Library.PcbLib
DB-0053 | JACK 3.5mm | Jack Audio 3.5mm PJ-320D PJ320D Hàn Board chân dán | CONNECTOR | N/A | N/A | N/A | SMD | SMD | Điện tử Minh Nguyên | Jack Audio 3.5mm PJ-320D PJ320D Hàn Board chân dán | https://chipn24.com/g30-jack-audio-3-5mm-pj-320d-pj320d-han-board-chan-dan-id2179.html | JACK_3.5 | .\Database_Library\Library.SchLib | JACK_3.5 | .\Database_Library\Library.PcbLib
DB-0054 | CONNECTOR_4 | Hàng Rào Đực Đơn 2.54mm 40 Chân 1 Hàng Cao 11.2mm Xuyên Lỗ | CONNECTOR | N/A | N/A | N/A | TFT | TFT | THEGIOIIC | Hàng Rào Đực Đơn 2.54mm 40 Chân 1 Hàng Cao 11.2mm Xuyên Lỗ | https://www.thegioiic.com/hang-rao-duc-don-2-54mm-40-chan-1-hang-cao-11-2mm-xuyen-lo | CON-3 | .\Database_Library\Library.SchLib | CON-3 | .\Database_Library\Library.PcbLib
DB-0055 | CONNECTOR_8 | Hàng Rào Đực Đơn 2.54mm 40 Chân 1 Hàng Cao 11.2mm Xuyên Lỗ | CONNECTOR | N/A | N/A | N/A | TFT | TFT | THEGIOIIC | Hàng Rào Đực Đơn 2.54mm 40 Chân 1 Hàng Cao 11.2mm Xuyên Lỗ | https://www.thegioiic.com/hang-rao-duc-don-2-54mm-40-chan-1-hang-cao-11-2mm-xuyen-lo | CON-8 | .\Database_Library\Library.SchLib | CON-8 | .\Database_Library\Library.PcbLib
DB-0056 | 22uF | CAPACITOR SMD 22uF 50V 10% 0805 | CAPACITOR | N/A | 22uF | 10% | SMD | 0805 | THEGIOIIC | Tụ Gốm 0805 22uF 6.3V | https://www.thegioiic.com/tu-gom-0805-22uf-6-3v | CAPACITOR | .\Database_Library\Library.SchLib | CAPCER 0805 SMD | .\Database_Library\Library.PcbLib
DB-0057 | 200R | RESISTOR SMD 200R OHM 5% 125mW 0805 | RESISTOR | 125mW | 200R | 5% | SMD | 0805 | THEGIOIIC | Điện Trở 200 Ohm 0805 5% | https://www.thegioiic.com/dien-tro-200-ohm-0805-5- | RESISTOR | .\Database_Library\Library.SchLib | RESC 0805 SMD | .\Database_Library\Library.PcbLib
DB-0058 | 10uF | CAPACITOR SMD 10uF 25V 10% 0805 | CAPACITOR | N/A | 10uF | 10% | SMD | 0805 | THEGIOIIC | Tụ Gốm 0805 10uF 25V | https://www.thegioiic.com/tu-gom-0805-10uf-25v | CAPACITOR | .\Database_Library\Library.SchLib | CAPCER 0805 SMD | .\Database_Library\Library.PcbLib
DB-0059 | 33KR | RESISTOR SMD 33KR OHM 1% 125mW 0805 | RESISTOR | 125mW | 33KR | 1% | SMD | 0805 | THEGIOIIC | Điện Trở 24 KOhm 0805 Điện Trở 33 KOhm 0805 1% | https://www.thegioiic.com/dien-tro-33-kohm-0805-1- | RESISTOR | .\Database_Library\Library.SchLib | RESC 0805 SMD | .\Database_Library\Library.PcbLib
DB-0060 | JACK_3.5_5P | PJ-327A Cổng Audio 3.5mm 3 Cực 5 Chân Dán SMD | N/A | N/A | N/A | N/A | SMD | PJ-327A | THEGIOIIC | PJ-327A Cổng Audio 3.5mm 3 Cực 5 Chân Dán SMD | https://www.thegioiic.com/pj-327a-cong-audio-3-5mm-3-cuc-5-chan-dan-smd | PJ-327A-5P | .\Database_Library\Library.SchLib | PJ-327A | .\Database_Library\Library.PcbLib
DB-0061 | 10uF | CAPACITOR ALU SMD 10uF 6.3V 20% 6377 | CAPACITOR ALU | N/A | 10uF | N/A | SMD | 6377 | THEGIOIIC | Tụ Nhôm SMD 100uF 35V 6.3x7.7mm | https://www.thegioiic.com/-thanh-ly-tu-nhom-smd-100uf-35v-6-3x7-7mm | CAPACITOR ALU | .\Database_Library\Library.SchLib | CAP ALU 6377 | .\Database_Library\Library.PcbLib
DB-0062 | RT9013 | IC REG LINEAR 3.3V 500MA SOT23-5 | IC | N/A | N/A | N/A | SMD | SOT-23-5 | THEGIOIIC | RT9013-33GB IC Ổn Áp 3.3V 500mA SOT-23-5 | https://www.thegioiic.com/rt9013-33gb-ic-on-ap-3-3v-500ma-sot-23-5 | RT9013 | .\Database_Library\Library.SchLib | SOT-23-5 | .\Database_Library\Library.PcbLib
DB-0063 | 1uF | CAPACITOR SMD 1uF 16V 10% 0805 | CAPACITOR | N/A | 1uF | 10% | SMD | 0805 | THEGIOIIC | Tụ Gốm 0805 1uF 16V | https://www.thegioiic.com/tu-gom-0805-1uf-16v | CAPACITOR | .\Database_Library\Library.SchLib | CAPCER 0805 SMD | .\Database_Library\Library.PcbLib
DB-0064 | XTAL_32.786K | CRYSTAL 32.7680KHZ 12.5PF SMD | XTAL | N/A | 32.7680KHZ | N/A | SMD | 4-SOJ | THEGIOIIC | Thạch Anh 32.768KHz MC-306 4 Chân | https://www.thegioiic.com/thach-anh-32-768khz-mc-306-4-chan | XTAL_4 | .\Database_Library\Library.SchLib | 4-SOJ | .\Database_Library\Library.PcbLib
DB-0065 | 20R | RESISTOR SMD 20R OHM 1% 100mW 0603 | RESISTOR | 100mW | 20R | 1% | SMD | 0603 | THEGIOIIC | Điện Trở 20 Ohm 0603 1% | https://www.thegioiic.com/dien-tro-20-ohm-0603-1- | RESISTOR | .\Database_Library\Library.SchLib | RESC 0603(1608) SMD | .\Database_Library\Library.PcbLib
DB-0066 | 20KR | RESISTOR SMD 20KR OHM 1% 100mW 0805 | RESISTOR | 125mW | 20KR | 1% | SMD | 0805 | THEGIOIIC | Điện Trở 20 KOhm 0805 1% | https://www.thegioiic.com/dien-tro-20-kohm-0805-1- | RESISTOR | .\Database_Library\Library.SchLib | RESC 0805 SMD | .\Database_Library\Library.PcbLib
DB-0067 | 220nF | CAPACITOR SMD 220nF 50V 10% 0805 | CAPACITOR | N/A | 220nF | 10% | SMD | 0805 | THEGIOIIC | Tụ Gốm 0805 220nF 50V | https://www.thegioiic.com/tu-gom-0805-220nf-50v | CAPACITOR | .\Database_Library\Library.SchLib | CAPCER 0805 SMD | .\Database_Library\Library.PcbLib
DB-0068 | 36KR | RESISTOR SMD 36KR OHM 5% 100mW 0805 | RESISTOR | 125mW | 36KR | 5% | SMD | 0805 | THEGIOIIC | Điện Trở 36 KOhm 0805 5% | https://www.thegioiic.com/dien-tro-36-kohm-0805-5- | RESISTOR | .\Database_Library\Library.SchLib | RESC 0805 SMD | .\Database_Library\Library.PcbLib
DB-0069 | Transistor PNP | 2SA1015LT1-BA Transistor PNP 50V 0.15A 3 Chân SOT-23 | Transistor | N/A | N/A | N/A | SMD | SOT23-3 | THEGIOIIC | 2SA1015LT1-BA Transistor PNP 50V 0.15A 3 Chân SOT-23 | https://www.thegioiic.com/2sa1015lt1-ba-transistor-pnp-50v-0-15a-3-chan-sot-23 | PNP | .\Database_Library\Library.SchLib | SOT23-3 | .\Database_Library\Library.PcbLib
DB-0070 | Transistor NPN | MMBT3904-1AM Transistor NPN 40V 0.2A 3 Chân SOT-23 | Transistor | N/A | N/A | N/A | SMD | SOT23-4 | THEGIOIIC | MMBT3904-1AM Transistor NPN 40V 0.2A 3 Chân SOT-23 | https://www.thegioiic.com/mmbt3904-1am-transistor-npn-40v-0-2a-3-chan-sot-23 | NPN | .\Database_Library\Library.SchLib | SOT23-3 | .\Database_Library\Library.PcbLib
DB-0071 | STM32F407VET6 | IC MCU 32BIT 512KB FLASH 100LQFP | MCU | N/A | N/A | N/A | SMD | 100LQFP | THEGIOIIC |  |  | STM32F407VET6 | .\Database_Library\Library.SchLib | 100LQFP | .\Database_Library\Library.PcbLib
DB-0072 | HOL CR2032 | BS-6 Đế Pin CR2032 CR2025 Dán SMD | HOLDER BAT | N/A | CR2032 3V | N/A | SMD | SMD | THEGIOIIC | BS-6 Đế Pin CR2032 CR2025 Dán SMD | https://www.thegioiic.com/bs-6-de-pin-cr2032-cr2025-dan-smd | HOLDER BAT | .\Database_Library\Library.SchLib | HOLDER BAT | .\Database_Library\Library.PcbLib
DB-0073 | XTAL_8MHZ | Thạch Anh 8MHz 5032 4 Chân SMD | XTAL | 8MHz | N/A | N/A | SMD | 5032 | THEGIOIIC | Thạch Anh 8MHz 5032 4 Chân SMD | https://www.thegioiic.com/thach-anh-8mhz-5032-4-chan-smd | XTAL 8MHZ | .\Database_Library\Library.SchLib | XTAL_5032 | .\Database_Library\Library.PcbLib
DB-0074 | Điện Trở 1 MOhm 0805 1% | RESISTOR SMD 10 MOHM 1% 100mW 0805 | RESISTOR | 100mW | 1MR | 1% | SMD | 0805 | THEGIOIIC | Điện Trở 1 MOhm 0805 1% | https://www.thegioiic.com/dien-tro-1-mohm-0805-1- | RESISTOR | .\Database_Library\Library.SchLib | CAPCER 0805 SMD | .\Database_Library\Library.PcbLib
DB-0075 | 12pF | CAPACITOR SMD 12pF 50V 10% 0805 | CAPACITOR | N/A | 12pF | 10% | SMD | 0805 | THEGIOIIC | Tụ Gốm 0805 12pF 50V | https://www.thegioiic.com/tu-gom-0805-4-7uf-50v | CAPACITOR | .\Database_Library\Library.SchLib | CAPCER 0805 SMD | .\Database_Library\Library.PcbLib
DB-0076 | 120R@100kHz | CBW201209U121T Ferrite Beads 2A 120 Ohm 0805 | FERRITE BEADS | N/A | 120R@100kHz | N/A | SMD | 0805 | THEGIOIIC | CBW201209U121T Ferrite Beads 2A 120 Ohm 0805 | https://www.thegioiic.com/cbw201209u121t-ferrite-beads-2a-120-ohm-0805 | FB | .\Database_Library\Library.SchLib | FB 0805 | .\Database_Library\Library.PcbLib
DB-0077 | DC5521 Đầu Nối Nguồn DC Cái 5521 Hàn PCB Kim 2.1mm | DC5521 Đầu Nối Nguồn DC Cái 5521 Hàn PCB Kim 2.1mm | JACK | 9W | JACK DC 1A | N/A | TFT | 2.1mm | THEGIOIIC | DC5521 Đầu Nối Nguồn DC Cái 5521 Hàn PCB Kim 2.1mm | https://www.thegioiic.com/dc5521-dau-noi-nguon-dc-cai-5521-han-pcb-kim-2-1mm | JACK 2.1 | .\Database_Library\Library.SchLib | JACK_2.1_TH | .\Database_Library\Library.PcbLib
DB-0078 | SMAJ12A | TVS DIODE 12V 19.9V DO214AC | DIODE | N/A | 12V 19.9V | N/A | SMD | SMA | DIGIKEY | TVS DIODE 5VWM 9.2VC SMA | https://www.digikey.com/en/products/detail/diodes-incorporated/smaj5-0a-13/278666 | SMAJ12 | .\Database_Library\Library.SchLib | DO-214AC | .\Database_Library\Library.PcbLib
DB-0079 | Tụ Gốm 0603 10nF 50V | CAPACITOR SMD 0.01uF 50V 10% 0603 | CAPACITOR | N/A | 10nF | 10% | SMD | 0603 | THEGIOIIC | Tụ Gốm 0603 10nF 50V | https://www.thegioiic.com/tu-gom-0603-100nf-0-1uf-25v | CAPACITOR | .\Database_Library\Library.SchLib | CAPCER 0805 SMD | .\Database_Library\Library.PcbLib
DB-0080 | LM393DT | IC COMPARATOR 2 DIFF 8SOIC | COMPARATOR | N/A | LM393DT | N/A | SMD | 8-SOIC | DIGIKEY | IC AUDIO 2 CIRCUIT 8SOIC | https://www.digikey.com/en/products/detail/texas-instruments/OPA2134UA | LM393DT | .\Database_Library\Library.SchLib | 8-SOIC-OPA
DB-0081 | 1KR | RESISTOR SMD 1KR OHM 1% 100mW 0603 | RESISTOR | 100mW | 1KR | 1% | SMD | 0603 | THEGIOIIC | Điện Trở 1 KOhm 0603 1% | https://www.thegioiic.com/dien-tro-1-kohm-0603-1- | RESISTOR | .\Database_Library\Library.SchLib | RESC 0603(1608) SMD | .\Database_Library\Library.PcbLib
DB-0082 | 0R | RESISTOR SMD 0KR OHM 1% 100mW 1206 | RESISTOR | 100mW | 0KR | 1% | SMD | 1206 | THEGIOIIC | Điện Trở 0 Ohm 1206 1% | https://www.thegioiic.com/dien-tro-0-ohm-1206-1- | RESISTOR | .\Database_Library\Library.SchLib | RESC 1206(3216) SMD | .\Database_Library\Library.PcbLib
DB-0083 | SW 2A | SS-12F23G4 Công Tắc Trượt 5 Chân Xuyên Lỗ ON-OFF Chỉnh Ngang 1P2T 2A | SLIDE SWITCH | 2A | SW-2A | N/A | TFT | SW-TH | THEGIOIIC | SS-12F23G4 Công Tắc Trượt 5 Chân Xuyên Lỗ ON-OFF Chỉnh Ngang 1P2T 2A | https://www.thegioiic.com/ss-12f23g4-cong-tac-truot-5-chan-xuyen-lo-on-off-chinh-ngang-1p2t-2a | SLIDE-SW | .\Database_Library\Library.SchLib | SLIDE-SW | .\Database_Library\Library.PcbLib
DB-0084 | CONNECTOR_6 | Hàng Rào Đực Đơn 2.54mm 40 Chân 1 Hàng Cao 11.2mm Xuyên Lỗ | CONNECTOR | N/A | CON-6 | N/A | TFT | TFT | THEGIOIIC | Hàng Rào Đực Đơn 2.54mm 40 Chân 1 Hàng Cao 11.2mm Xuyên Lỗ | https://www.thegioiic.com/hang-rao-duc-don-2-54mm-40-chan-1-hang-cao-11-2mm-xuyen-lo | CON-6 | .\Database_Library\Library.SchLib | CON-6 | .\Database_Library\Library.PcbLib
DB-0085 | CONNECTOR_2 | Hàng Rào Đực Đơn 2.54mm 40 Chân 1 Hàng Cao 11.2mm Xuyên Lỗ | CONNECTOR | N/A | CON-2 | N/A | TFT | TFT | THEGIOIIC | Hàng Rào Đực Đơn 2.54mm 40 Chân 1 Hàng Cao 11.2mm Xuyên Lỗ | https://www.thegioiic.com/hang-rao-duc-don-2-54mm-40-chan-1-hang-cao-11-2mm-xuyen-lo | CON-2 | .\Database_Library\Library.SchLib | CON-2 | .\Database_Library\Library.PcbLib
DB-0086 | BAT54C |  |  |  | BAT54C |  |  |  |  |  |  | BAT54C | .\Database_Library\Library.SchLib | SOT23-3 | .\Database_Library\Library.PcbLib
DB-0087 | CH340G |  |  |  | CH340G |  |  |  |  |  |  | CH340G | .\Database_Library\Library.SchLib | SOP-16 | .\Database_Library\Library.PcbLib
DB-0088 | USB_TYPE_C |  | USB |  | USB_C |  |  |  |  |  |  | USB_C | .\Database_Library\Library.SchLib | TYPEC-16POS | .\Database_Library\Library.PcbLib
DB-0089 | XTAL_8MHZ | Thạch Anh 8MHz 5032 4 Chân SMD | XTAL | 8MHz | N/A | N/A | SMD | 5032 | THEGIOIIC | Thạch Anh 8MHz 5032 4 Chân SMD | https://www.thegioiic.com/thach-anh-12mhz-5032-4-chan-smd | XTAL 12MHZ | .\Database_Library\Library.SchLib | XTAL_5032 | .\Database_Library\Library.PcbLib
DB-0090
DB-0091
 |  |  |  |  |  |  |  |  |  |  |  |  |  | x

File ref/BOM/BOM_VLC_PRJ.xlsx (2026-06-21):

No | Manufacturer | Manufacturer P/N | Digikey P/N | Quanlity
1 | Texas Instruments | OPA380AID | 296-16859-5-ND | 6
2 | Texas Instruments | OPA350UA | OPA350UA-ND | 6
3 | Texas Instruments | OPA188AIDR | 296-41346-2-ND | 4
4 | Microchip Technology | TC4427AEOA | TC4427AEOA-ND | 4

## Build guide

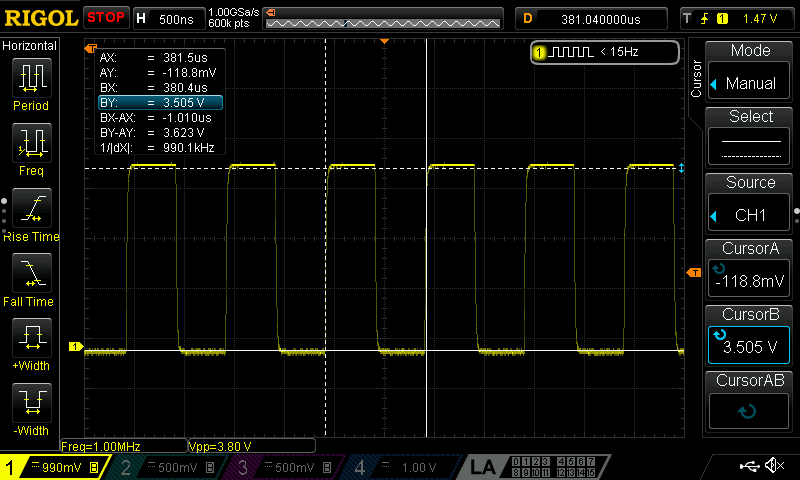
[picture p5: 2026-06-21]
ref/ING/DS1Z_QuickPrint17.png

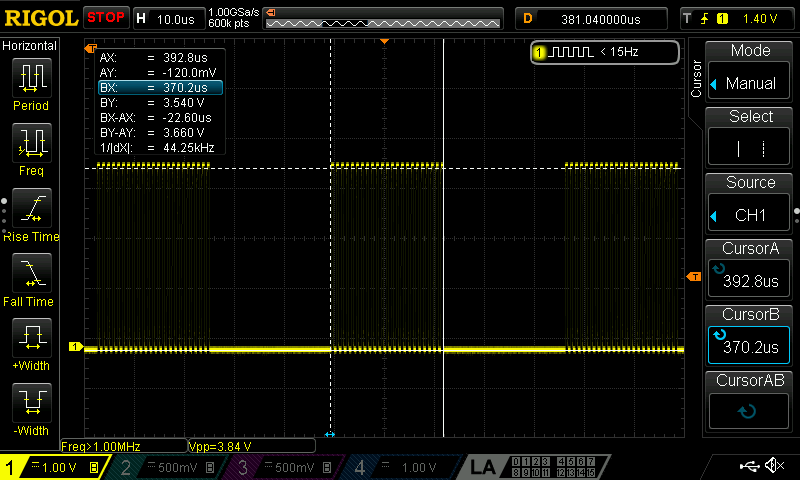
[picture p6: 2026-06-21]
ref/ING/DS1Z_QuickPrint18.png

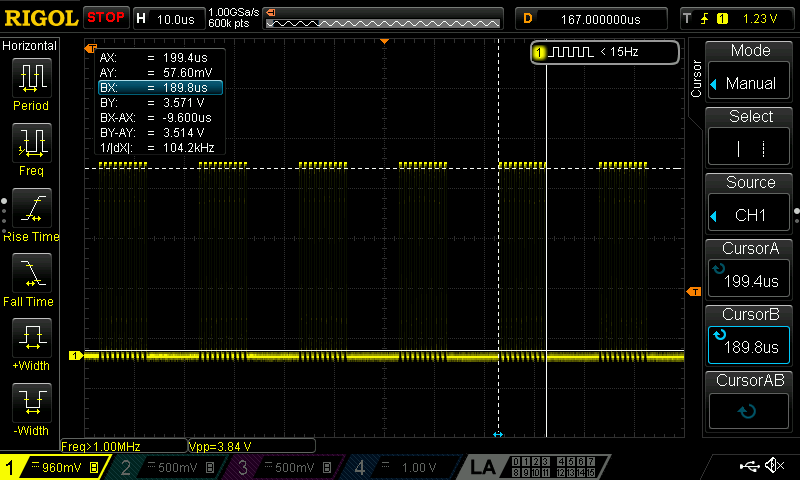
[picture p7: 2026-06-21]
ref/ING/DS1Z_QuickPrint21.png

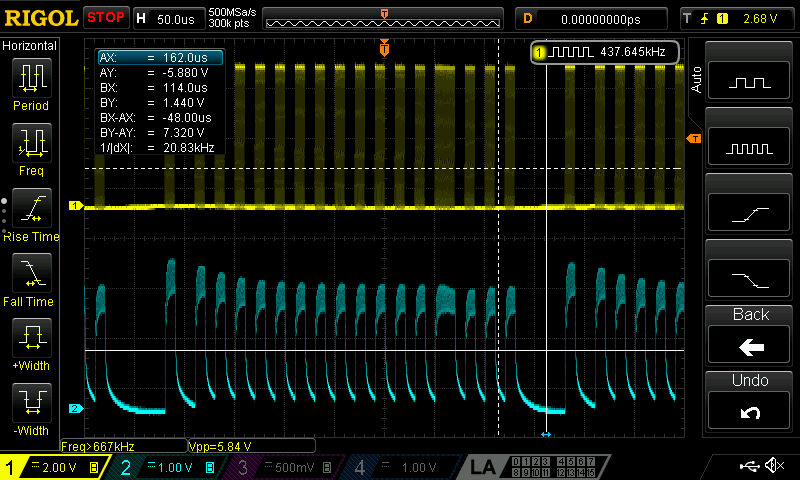
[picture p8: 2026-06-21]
ref/ING/DS1Z_QuickPrint8.png

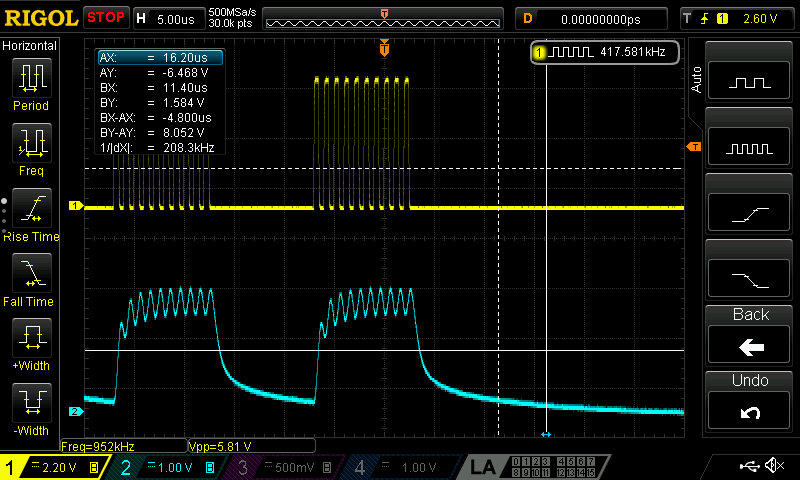
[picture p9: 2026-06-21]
ref/ING/DS1Z_QuickPrint4.png

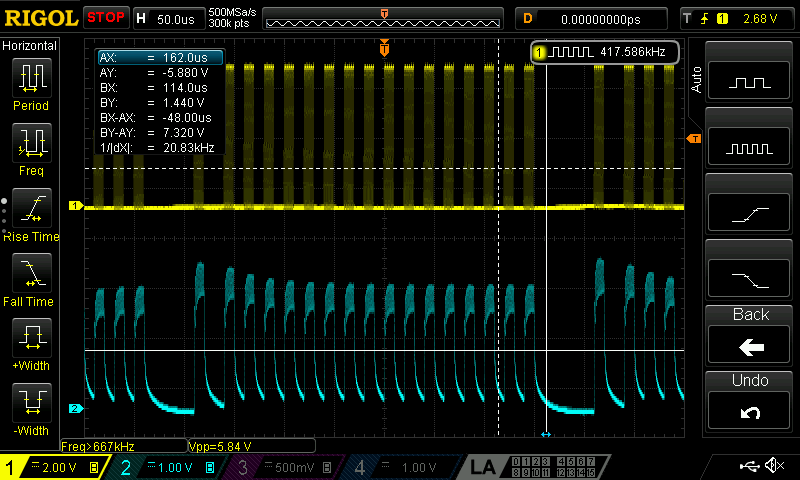
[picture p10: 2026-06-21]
ref/ING/DS1Z_QuickPrint9.png

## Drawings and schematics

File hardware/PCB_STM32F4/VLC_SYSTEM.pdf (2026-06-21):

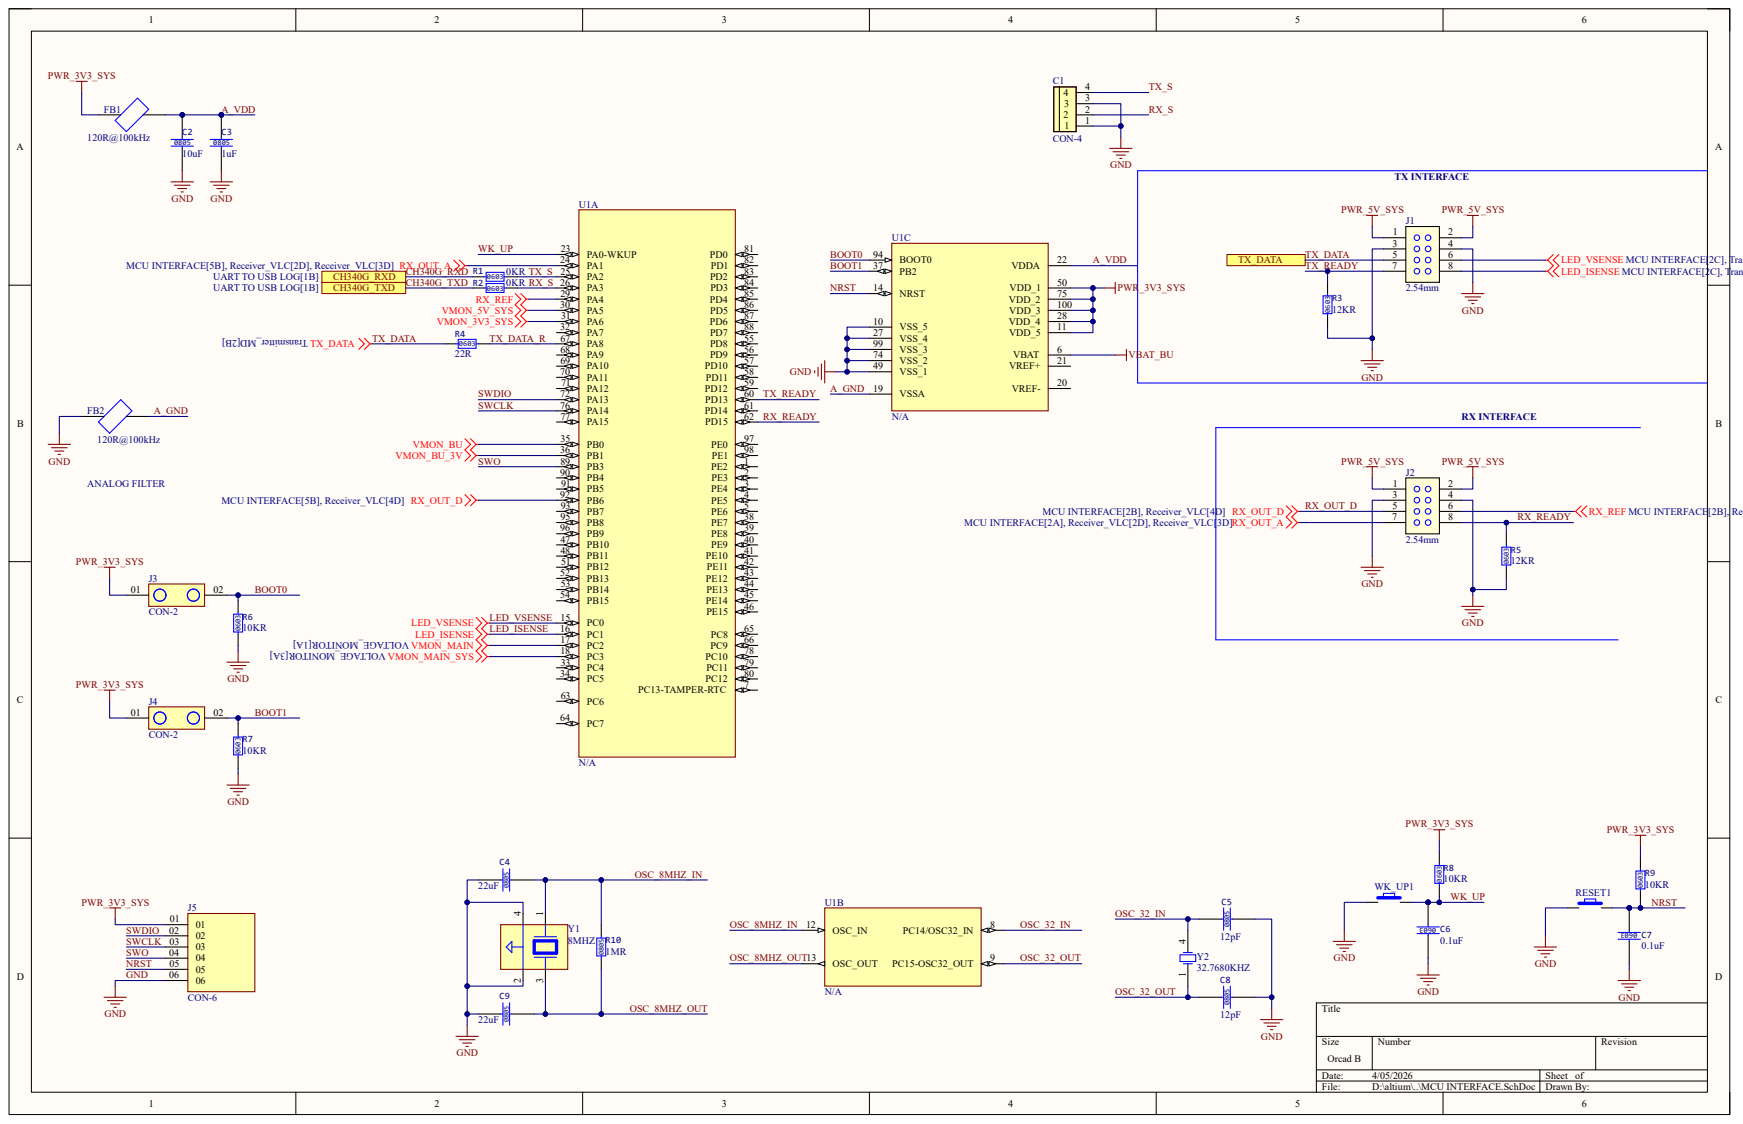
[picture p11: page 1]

# R25 0805 33KR

# POWER SUPPLY SYSTEM

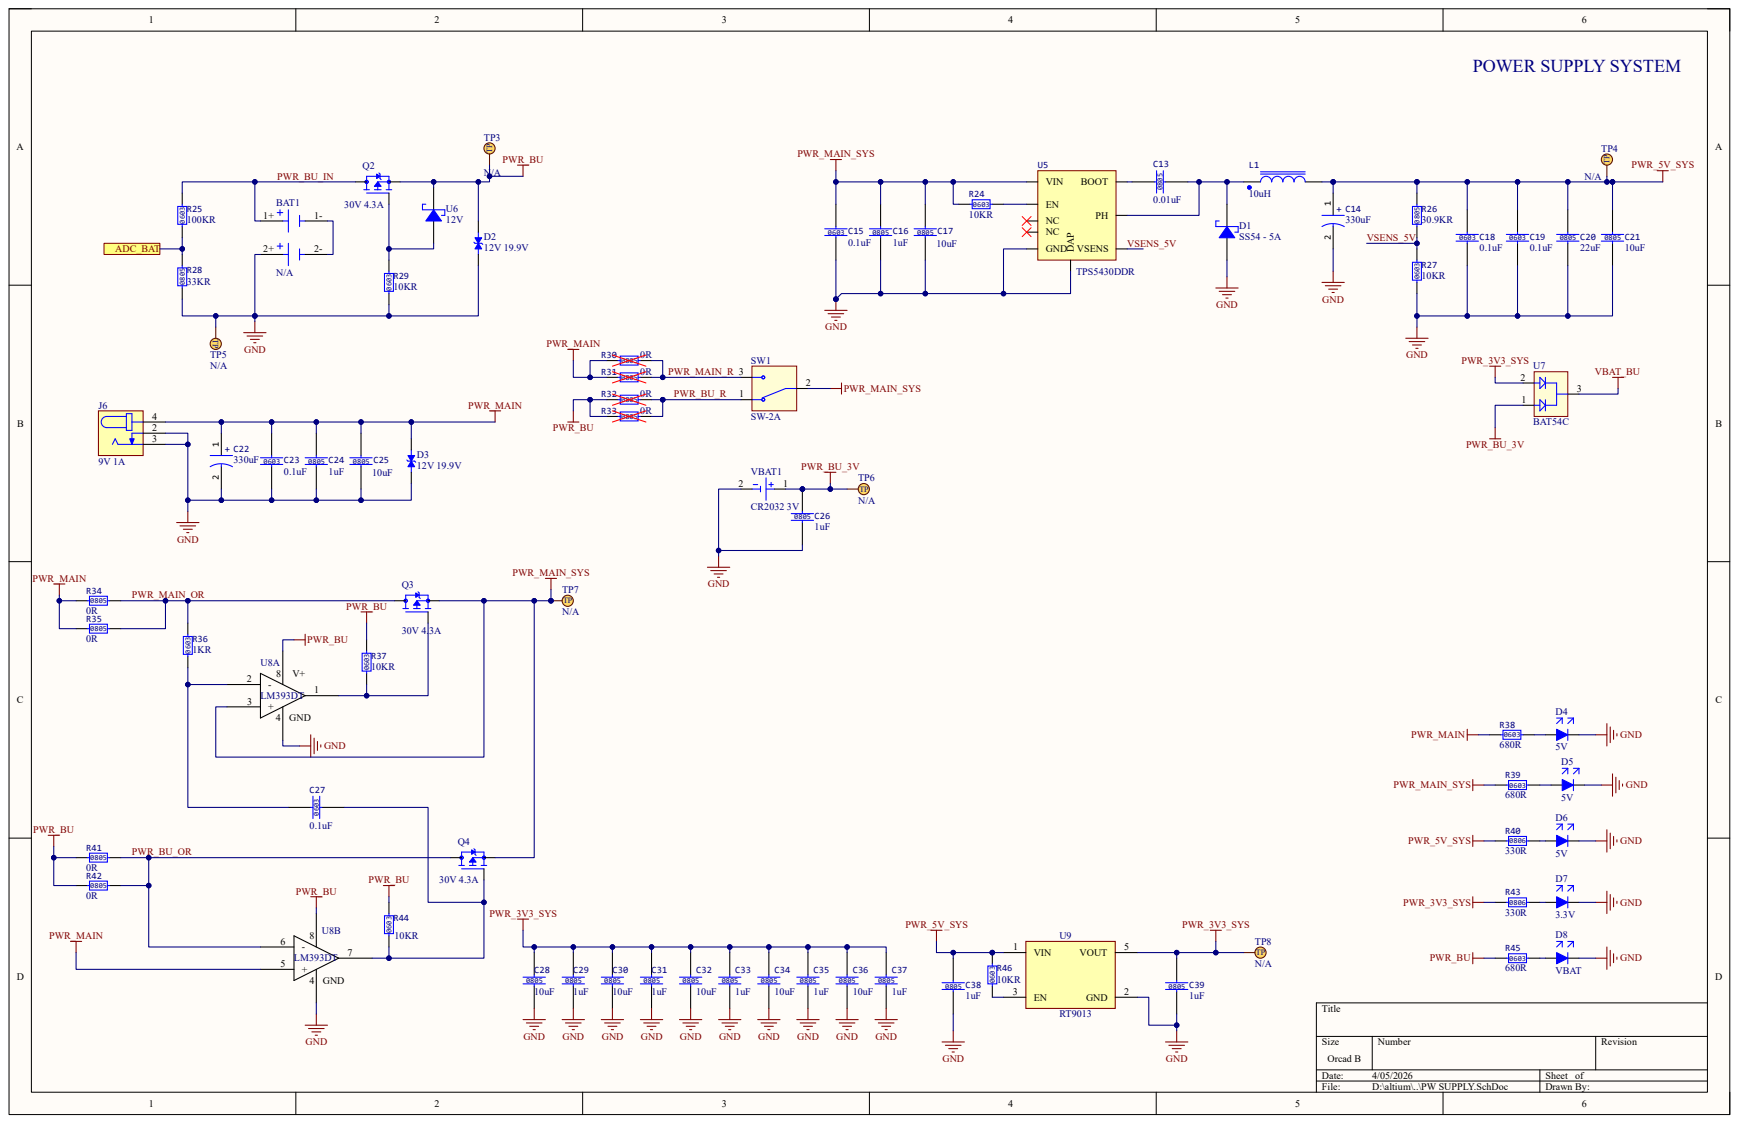
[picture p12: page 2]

A A

VBUS A4_B9 | CC1 | A5

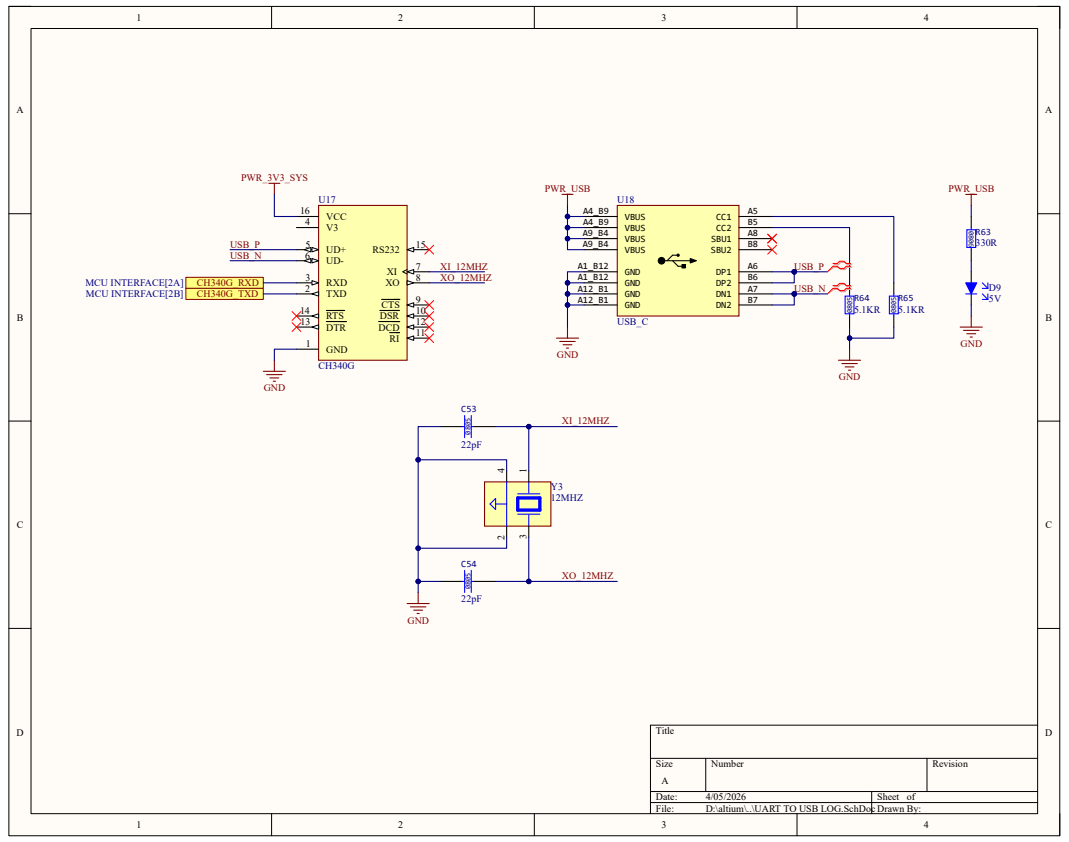
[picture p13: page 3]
Title; Size; Number; Revision; File:; D:\altium\..\UART TO USB LOG.SchDoc Drawn By:; GND A1_B12; SBU1; A8 VBUS A4_B9; GND A1_B12 GND A12_B1; VBUS A9_B4; SBU2; B8 VBUS A9_B4; GND A12_B1; USB_C; CTS; DSR; DCD; VCC 16 V3 4; RXD 3 TXD 2; RTS 14 DTR 13; GND 1; 12MHZ; XI_12MHZ XO_12MHZ; XO_12MHZ; XI_12MHZ 0805; GND; PWR_USB; USB_P; USB_N; D9 MCU INTERFACE[2A] CH340G_RXD MCU INTERFACE[2B] CH340G_TXD; PWR_3V3_SYS

A A

## PWR_5V_SYS 080530.9KR

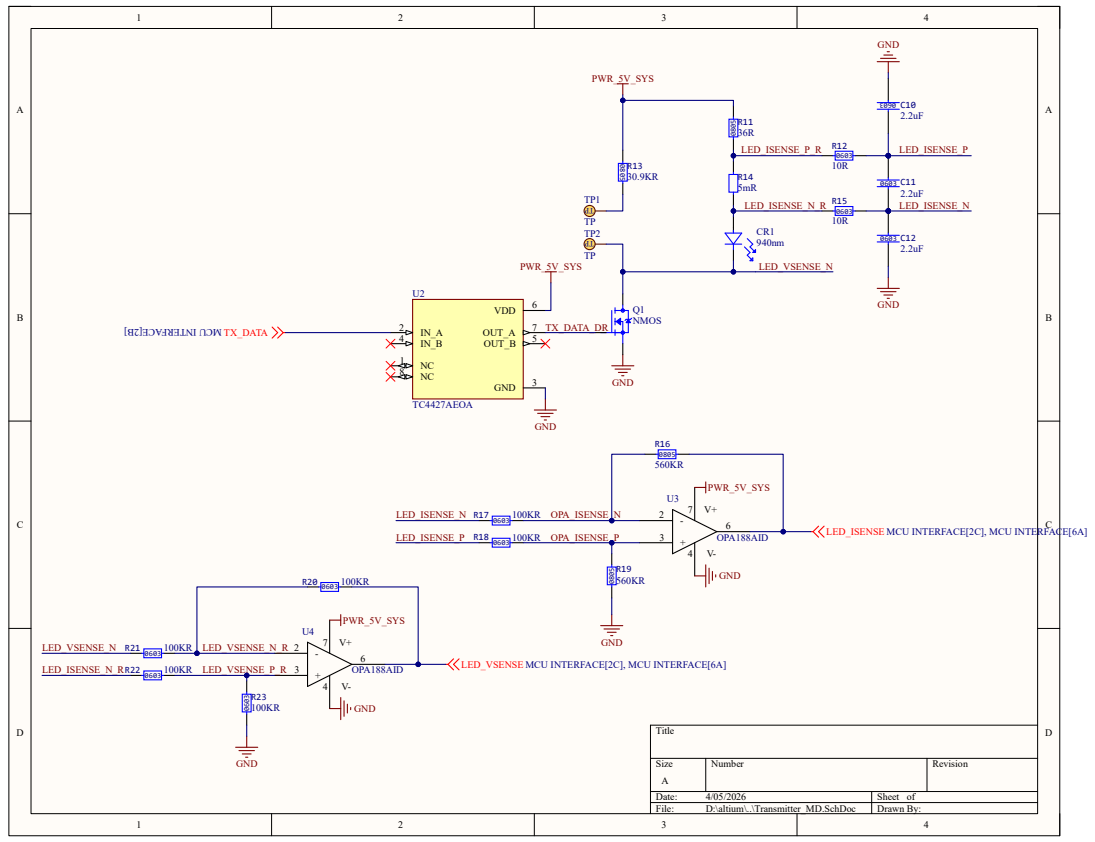
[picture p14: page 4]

LED_ISENSE MCU INTERFACE[2C], MCU INTERFACE[6A]

LED_VSENSE MCU INTERFACE[2C], MCU INTERFACE[6A]

# TP9 TP

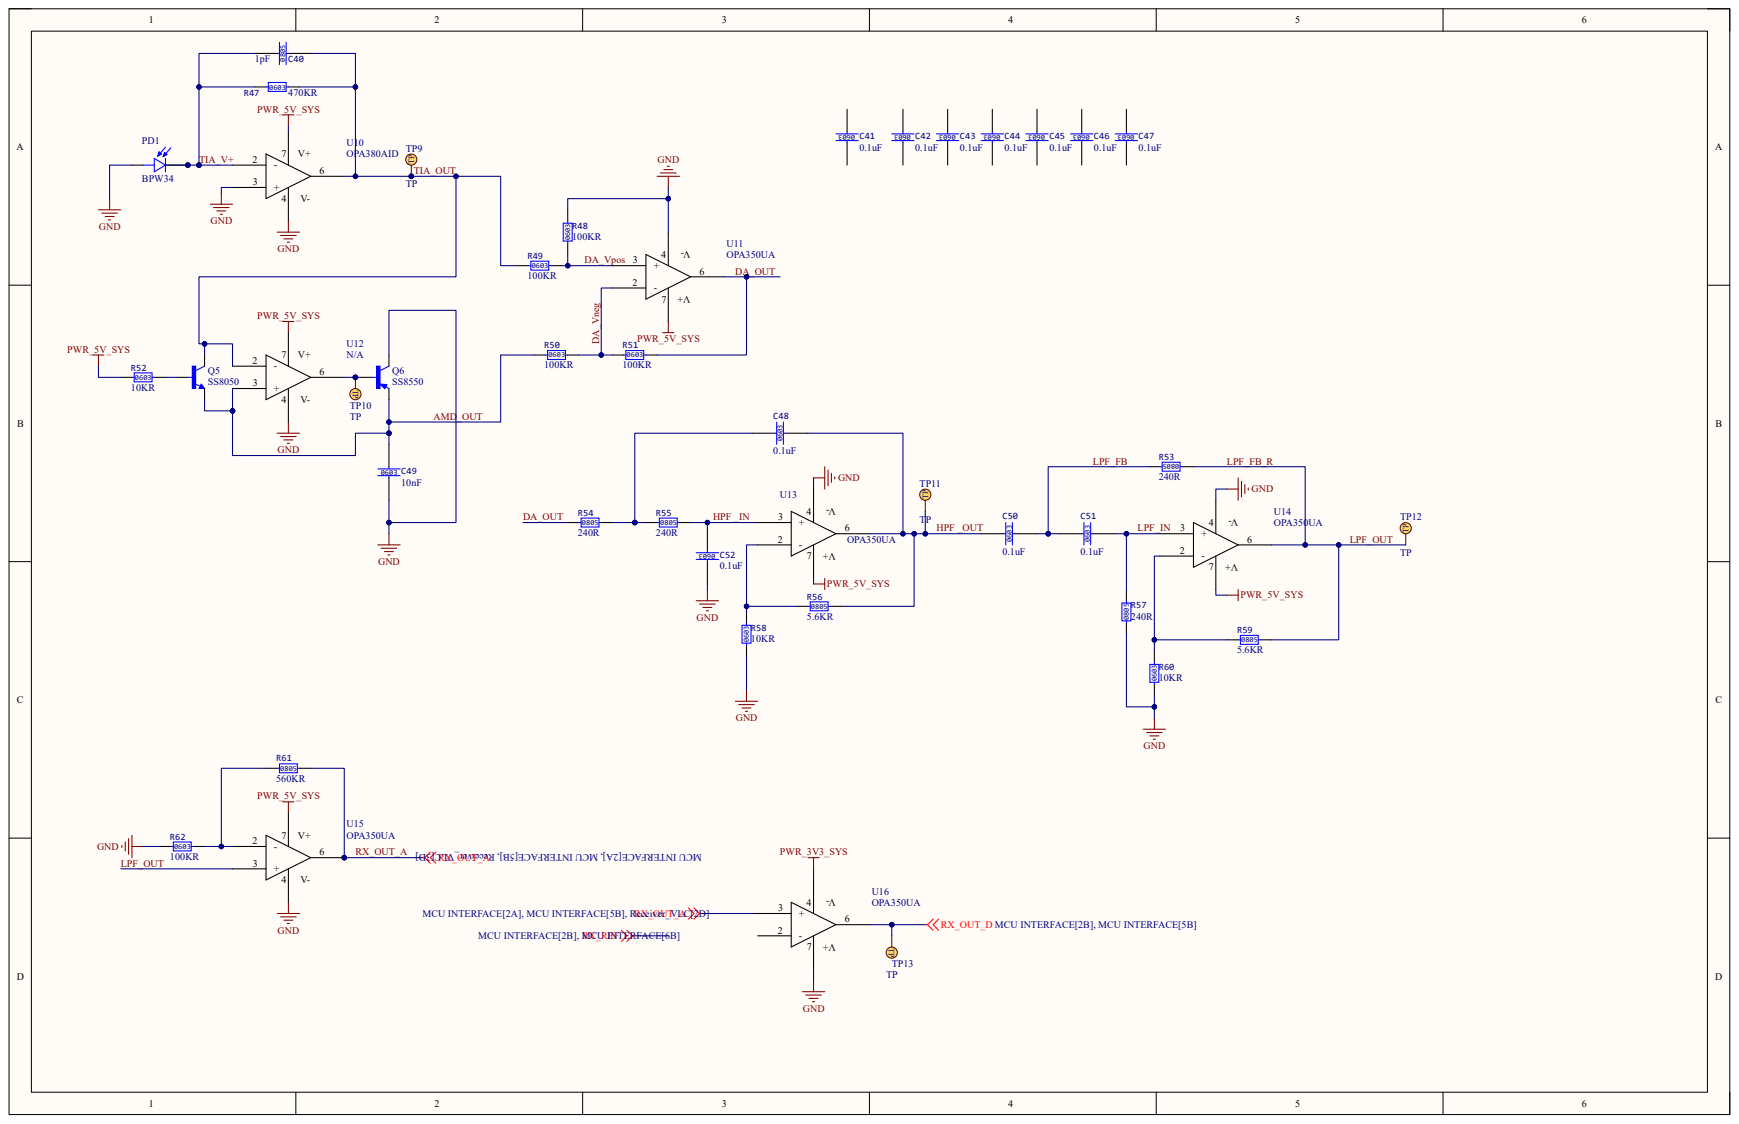
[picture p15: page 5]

MCU INTERFACE[2A], MCU INTERFACE[5B], Receiver_VLC[2D] RX_OUT_A

RX_OUT_D MCU INTERFACE[2B], MCU INTERFACE[5B]

MCU INTERFACE[2B], MCU INTERFACE[6B] RX_REF

A A

# File: D:\altium\..\VOLTAGE_MONITOR.SchDocDrawn By: ⁰⁶⁰³ 10KR

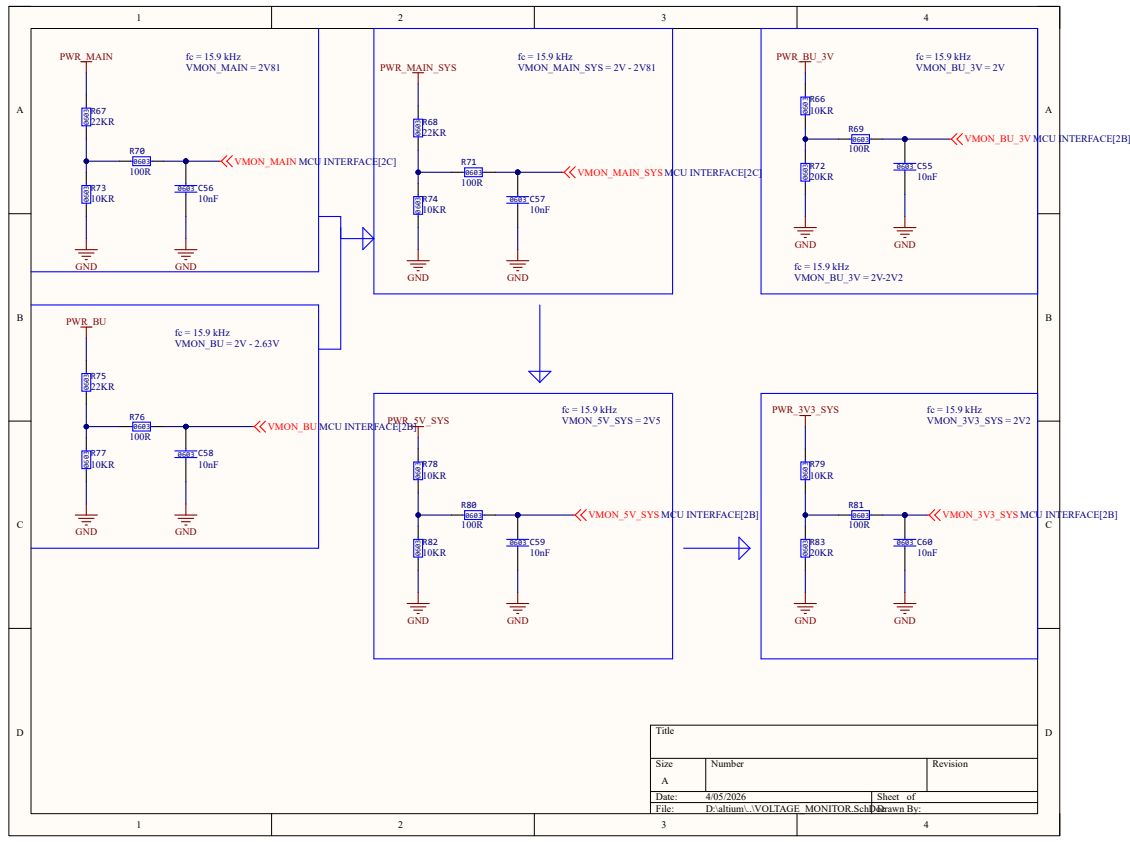
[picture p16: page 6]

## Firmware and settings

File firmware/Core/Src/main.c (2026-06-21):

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
/* Includes ------------------------------------------------------------------*/
#include "main.h"

/* USER CODE BEGIN Includes */
#include "app_tasks.h"
/* USER CODE END Includes */

ADC_HandleTypeDef hadc1;
DMA_HandleTypeDef hdma_adc1;

DAC_HandleTypeDef hdac;

TIM_HandleTypeDef htim1;
TIM_HandleTypeDef htim2;

UART_HandleTypeDef huart2;

/* USER CODE BEGIN PV */
TIM_HandleTypeDef htim4;

/* USER CODE END PV */

void SystemClock_Config(void);
static void MX_GPIO_Init(void);
static void MX_DMA_Init(void);
static void MX_TIM1_Init(void);
static void MX_TIM2_Init(void);
static void MX_ADC1_Init(void);
static void MX_USART2_UART_Init(void);
static void MX_DAC_Init(void);
/* USER CODE BEGIN PFP */
static void MX_TIM4_Init(void);

/* USER CODE END PFP */

/* USER CODE BEGIN 0 */
static void MX_TIM4_Init(void)
{
  TIM_ClockConfigTypeDef sClockSourceConfig = {0};
  TIM_IC_InitTypeDef sConfigIC = {0};
  TIM_SlaveConfigTypeDef sSlaveConfig = {0};
  GPIO_InitTypeDef GPIO_InitStruct = {0};

  __HAL_RCC_GPIOB_CLK_ENABLE();
  __HAL_RCC_TIM4_CLK_ENABLE();

  GPIO_InitStruct.Pin = GPIO_PIN_6;
  GPIO_InitStruct.Mode = GPIO_MODE_AF_PP;
  GPIO_InitStruct.Pull = GPIO_NOPULL;
  GPIO_InitStruct.Speed = GPIO_SPEED_FREQ_VERY_HIGH;
  GPIO_InitStruct.Alternate = GPIO_AF2_TIM4;
  HAL_GPIO_Init(GPIOB, &GPIO_InitStruct);

  htim4.Instance = TIM4;
  htim4.Init.Prescaler = 0;
  htim4.Init.CounterMode = TIM_COUNTERMODE_UP;
  htim4.Init.Period = 0xFFFFU;
  htim4.Init.ClockDivision = TIM_CLOCKDIVISION_DIV1;
  htim4.Init.AutoReloadPreload = TIM_AUTORELOAD_PRELOAD_DISABLE;
  if (HAL_TIM_Base_Init(&htim4) != HAL_OK)
  {
    Error_Handler();
  }

  sClockSourceConfig.ClockSource = TIM_CLOCKSOURCE_INTERNAL;
  if (HAL_TIM_ConfigClockSource(&htim4, &sClockSourceConfig) != HAL_OK)
  {
    Error_Handler();
  }

  if (HAL_TIM_IC_Init(&htim4) != HAL_OK)
  {
    Error_Handler();
  }

  sConfigIC.ICPolarity = TIM_INPUTCHANNELPOLARITY_RISING;
  sConfigIC.ICSelection = TIM_ICSELECTION_DIRECTTI;
  sConfigIC.ICPrescaler = TIM_ICPSC_DIV1;
  sConfigIC.ICFilter = 0;
  if (HAL_TIM_IC_ConfigChannel(&htim4, &sConfigIC, TIM_CHANNEL_1) != HAL_OK)
  {
    Error_Handler();
  }

  sSlaveConfig.SlaveMode = TIM_SLAVEMODE_EXTERNAL1;
  sSlaveConfig.InputTrigger = TIM_TS_TI1FP1;
  sSlaveConfig.TriggerPolarity = TIM_TRIGGERPOLARITY_RISING;
  sSlaveConfig.TriggerFilter = 0;
  if (HAL_TIM_SlaveConfigSynchronization(&htim4, &sSlaveConfig) != HAL_OK)
  {
    Error_Handler();
  }
}

/* USER CODE END 0 */

/**
  * @brief  The application entry point.
  * @retval int
  */
int main(void)
{

  /* MCU Configuration--------------------------------------------------------*/

  /* Reset of all peripherals, Initializes the Flash interface and the Systick. */
  HAL_Init();

  /* Configure the system clock */
  SystemClock_Config();

  /* Initialize all configured peripherals */
  MX_GPIO_Init();
  MX_DMA_Init();
  MX_TIM1_Init();
  MX_TIM2_Init();
  MX_ADC1_Init();
  MX_USART2_UART_Init();
  MX_DAC_Init();
  /* USER CODE BEGIN 2 */
  MX_TIM4_Init();
  app_tasks_init(&huart2, &htim1, &htim2, &htim4, &hadc1, &hdac);
  app_tasks_start();
  /* USER CODE END 2 */

  /* Infinite loop */
  /* USER CODE BEGIN WHILE */
  while (1)
  {
    /* USER CODE END WHILE */

    /* USER CODE BEGIN 3 */
    app_tasks_process();
  }
  /* USER CODE END 3 */
}

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
/* USER CODE BEGIN 4 */
void HAL_TIM_PeriodElapsedCallback(TIM_HandleTypeDef *htim)
{
  if ((htim != 0) && (htim->Instance == TIM2))
  {
    app_tasks_on_timer_period_elapsed(htim);
  }
}

/* USER CODE END 4 */
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


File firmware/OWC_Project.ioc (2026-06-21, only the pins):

Mcu.UserName=STM32F407VETx
PA1.Signal=ADCx_IN1
PA13.Signal=SYS_JTMS-SWDIO
PA14.Signal=SYS_JTCK-SWCLK
PA2.Signal=USART2_TX
PA3.Signal=USART2_RX
PA4.Signal=COMP_DAC1_group
PA5.Signal=ADCx_IN5
PA6.Signal=ADCx_IN6
PA8.Signal=S_TIM1_CH1
PB0.Signal=ADCx_IN8
PB1.Signal=ADCx_IN9
PB6.Signal=GPIO_Input
PC0.Signal=ADCx_IN10
PC1.Signal=ADCx_IN11
PD13.Signal=GPIO_Input
PD15.Signal=GPIO_Input
PH0-OSC_IN.Signal=RCC_OSC_IN
PH1-OSC_OUT.Signal=RCC_OSC_OUT

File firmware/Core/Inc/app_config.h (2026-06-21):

#ifndef APP_CONFIG_H
#define APP_CONFIG_H

#include <stdint.h>

#define APP_BIT_RATE_HZ                100000U
#define APP_TIM2_TICK_HZ               100000U
#define APP_TIM2_ARR_100KHZ            839U

#define APP_TIM1_PWM_PERIOD            167U
#define APP_TIM1_CARRIER_CCR_ON        84U
#define APP_TIM1_CARRIER_CCR_OFF       0U

#define APP_RX_EXPECTED_EDGES_PER_BIT  10U
#define APP_RX_EDGE_THRESHOLD          6U
#define APP_RX_USE_EDGE_COUNTER        1U

#define APP_FRAME_PREAMBLE_BYTE        0xAAU
#define APP_FRAME_PREAMBLE_BYTES       3U
#define APP_FRAME_SYNC_BYTE            0xD5U
#define APP_MAX_PAYLOAD_LEN            32U
#define APP_RX_QUEUE_DEPTH             32U
#define APP_RX_ERROR_EVENT_QUEUE_DEPTH 16U

#define APP_BOARD_ROLE_TX_ONLY         0U
#define APP_BOARD_ROLE_RX_ONLY         1U
#define APP_BOARD_ROLE_TX_RX_LOOPBACK  2U

#define APP_BOARD_ROLE                 APP_BOARD_ROLE_TX_RX_LOOPBACK

#if (APP_BOARD_ROLE > APP_BOARD_ROLE_TX_RX_LOOPBACK)
#error "Invalid APP_BOARD_ROLE"
#endif

#define APP_DAC_DEFAULT_THRESHOLD_MV   1650U

#define APP_ADC_CHANNEL_COUNT          7U
#define APP_ADC_VREF_MV                3300U

#define APP_LOG_PERIOD_MS              1000U
#define APP_ERR_LOG_MAX_PER_PERIOD     5U
#define APP_ERR_BITS_MAX_PER_PERIOD    1U
#define APP_ERR_BITS_ENABLE            1U

#define APP_RTC_ENABLE                 1U
#define APP_RTC_USE_LSE                1U
#define APP_RTC_MAGIC                  0x32F4U
#define APP_RTC_DEFAULT_YEAR           2026U
#define APP_RTC_DEFAULT_MONTH          1U
#define APP_RTC_DEFAULT_DAY            1U
#define APP_RTC_DEFAULT_HOUR           0U
#define APP_RTC_DEFAULT_MIN            0U
#define APP_RTC_DEFAULT_SEC            0U
#define APP_RTC_LOG_ENABLE             1U

#endif

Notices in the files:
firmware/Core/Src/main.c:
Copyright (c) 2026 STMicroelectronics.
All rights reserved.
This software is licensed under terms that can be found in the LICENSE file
